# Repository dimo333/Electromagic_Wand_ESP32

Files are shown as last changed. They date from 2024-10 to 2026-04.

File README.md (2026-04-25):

# 🧙‍♂️ ESP32 手势识别魔杖项目

## 项目简介

这是一个基于 **ESP32 + MPU6050** 实现的 **手势识别电子魔杖** 项目。你可以参考本项目的文件，动手制作属于你自己的魔杖！

我还提供了训练代码，你可以根据自己设计的动作“训练法术”。如果你有更好的创意或代码，欢迎交流、学习与分享！

- 📘 [完整项目地址github](https://github.com/dimo333/Electromagic_Wand_ESP32)
- 📘 [完整项目地址gitee](https://gitee.com/dimo666/Electromagic_Wand_ESP32/tree/main)
- 📘 [PCB文件地址oshwhub](https://oshwhub.com/6dimo9/electromagic_wand_esp32)
---

## 🚀 快速开始

我已编写详细的图文教程和环境配置指南：

- 📘 [教程文档github](https://github.com/dimo333/Electromagic_Wand_ESP32/tree/main/docs/tutorial)
- 📘 [教程文档gitee](https://gitee.com/dimo666/Electromagic_Wand_ESP32/tree/main/docs/tutorial)
- 📺 [B站视频教程（基础演示）](https://www.bilibili.com/video/BV1NtwreXEzg)

---

## 🛠 遇到问题？

请尝试以下方法：

1. 仔细检查是否遗漏了教程中的某一步。
2. 根据[H_elp](https://github.com/dimo333/Electromagic_Wand_ESP32/tree/main/docs/H_elp)文档进行自救<br>
3. 复制错误信息，使用搜索引擎或 AI 工具查找答案。
4. 加入 QQ 群：**884880944**。
5. B站后台私信我：[dimo333](https://space.bilibili.com/)。
6. 发送邮件联系我：
   - 📧 dimo333mail@gmail.com（注意拼写）
   - 📧 3180405726@qq.com

---

## ✨ 魔杖具备哪些功能？

魔杖实现了基础的手势识别，基于此可扩展出以下功能：

- 📡 红外信号复制与发送（遥控家电）
- 🖱 模拟鼠标（如飞鼠操作）
- ⌨️ 模拟键盘（快捷输入）
- 📶 蓝牙 / WiFi 通信
  - 可接入 HomeAssistant 实现智能家居联动
  - 接入米家app控制米家设备

---

## 💰 硬件清单与预算

### 🔧 模块连接（推荐入门版）

- 成本约：**15 元**
- 组件清单：
  - ESP32-C3 SuperMini（4MB Flash）
  - MPU6050 陀螺仪模块
  - 按键模块（可选）

### 🛠 自制 PCB（进阶推荐）

- 成本约：**70 元**
- 推荐下单平台：嘉立创 / 立创商城
- 所需内容：
  - PCB 电路板（支持免费打样）
  - PCB 元件
  - 芯片：ESP32-C3FH4、MPU6050 等

---

## 🧞 想直接玩，有没有捷径？

有的，兄弟有的！不想动手，那就动点钱：

- 加入 QQ 群，问问有没有大佬愿意出售焊接好的板子。
- 私聊我，看看我这还有没有多余的现成板子。

---

## 📁 项目结构

```text
├── docs                # 项目文档、图文教程、使用说明
├── Software            # 软件代码（数据收集、训练等）
├── Hardware            # 原理图、电路板设计文件、3D外壳模型等硬件相关资料
├── 3D_Print            # 3D外壳模型
├── lib                # 库文件（如库压缩包、工具函数）
```
---
## 复刻路线
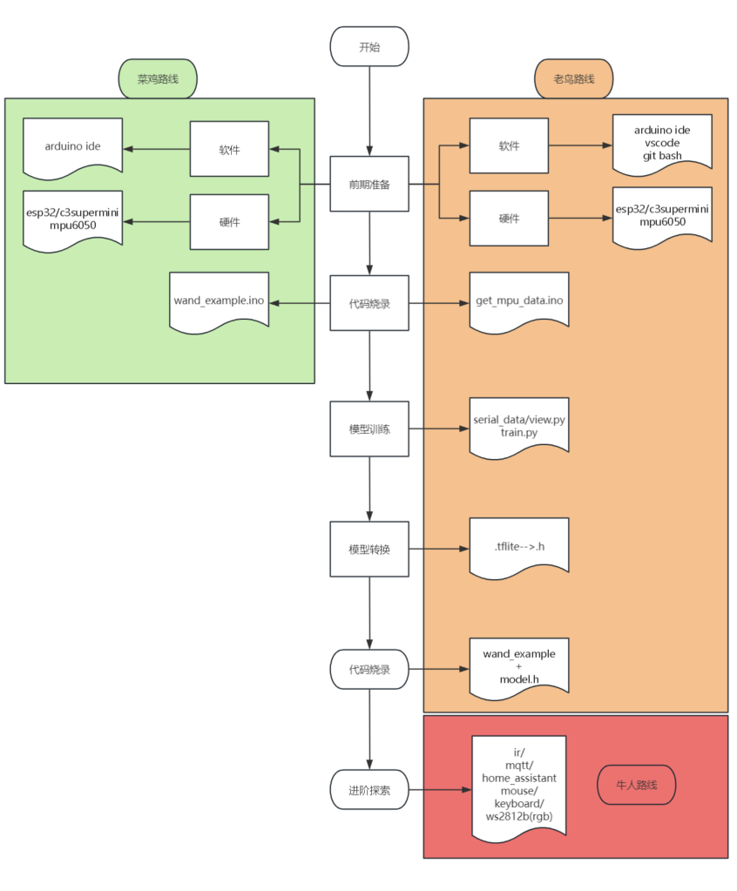
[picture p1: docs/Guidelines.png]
复刻路线


## 🤝 鸣谢与参考

* [MagicWand](https://github.com/Songyeyaosong/MagicWand) - 感谢其最早实现了赛博魔杖的底层功能，为本项目的二次开发提供了参考。
* [esp32_mouse_keyboard](https://github.com/asterics/esp32_mouse_keyboard) - 感谢其提供的 BLE 鼠标与键盘模拟功能，极大丰富了魔杖的交互能力。

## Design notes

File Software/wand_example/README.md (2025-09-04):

重要提醒：
wand是魔杖最终烧录进去的代码，记得检查一下代码靠下方有一个数据打印的输出，需要检查一下和自己使用的轴，getmpudata录数据的轴是不是同样的轴！！！！
在getmpudata里面：
Serial.print(Ox);
Serial.print(",");
Serial.print(Oz);
那么这就是使用的x和z轴，在wand底下找到和这个相似的代码，修改成一样的
在wand_example里面：  
input[i * input_dim] = Ox;
input[i * input_dim + 1] = Oz;
这一段就是输入轴的数据了，请务必保证和上面是对应的。

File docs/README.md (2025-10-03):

## 📁 文件结构

```text
├── H_elp                   # 自救指南
├── HomeAssistant-Mi_Home   # 如何连接HomeAssistant与米家
├── gestures                # 手势动作图片参考
├── others                  # 一些图片参考
├── tutorial                # 使用教程
├── Guidelines.png          # 一张简易的路线图
```
---
我花了很多时间和精力来编写这些教程，但仍然会有我无法预想到的bug存在。<br>
如果你在根据图文教程使用的过程中遇到了问题，<br>
可以按以下步骤来排查：<br>
1、反复检查是否遗漏哪一步步骤<br>
2、根据[H_elp](https://github.com/dimo333/Electromagic_Wand_ESP32/tree/main/docs/H_elp)文档进行自救<br>
3、通过QQ群进行提问（提问请按照群公告的格式来，这会更快地获得答复）<br>

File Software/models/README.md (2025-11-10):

models
===
简述：动作（手势）的模型与数据集<br>
来源：dimo333<br>

注意事项：<br>
代码版本较旧，部分参数可能并非最新最优，请自行修改<br>
1030_5为64hz2s  ox+oz轴   24年10月30日上传（旧版）<br>
0908_6为100hz2s oy+oz轴   25年09月08日上传（新版，亲测识别率有90%）<br>
0922_6为100hz2s oy+oz轴   25年09月22日上传（新版，手势幅度更大，更自然，亲测识别效果95%）
数据集中50组为一个动作（手势）数据，你可以直接使用我训练好的模型<br>
也可以单独使用数据集自行训练<br>
注意64hz需要将train中timesteps改为128，100hz改为200<br>

---

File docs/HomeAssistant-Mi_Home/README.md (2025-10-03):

## 📁 文件结构

```text
├── HomeAssistant_with_MI_Home      # Ha及米家搭建教程
├── BY-GT8_with_MI_Hoem             # 模块连接米家教程
├── BY-GT8                          # 模块手册
```
---

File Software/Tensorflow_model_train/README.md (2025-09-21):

Tensorflow_model_train
===
简述：用于训练动作（手势）的文件<br>
来源：dimo333<br>

使用方法：<br>
1、首先请确保你认真并仔细的看过了图文教程中关于环境安装的部分<br>
2、训练出来的模型文件是.tflite后缀，需要转成.h才能写进ESP32<br>
3、在lwindows的git bash（或者Linux系统）运行这段代码将.tflite转成.h：<br>
4、 xxd -i model.tflite > model.h

注意事项：<br>
代码版本较旧，部分参数可能并非最新最优，请自行修改<br>
动作（手势）训练涉及到魔杖的核心内容之一，其中动作（手势）数据的录入需要极大的耐心和定力。<br>
用群友的话来说“这是一场魔杖选择主人巫师的过程”<br>
所以请量力而行<br>

---
---

代码与工具<br>
===

serial_data.py<br>
简述：用于收集数据并转写至data_x/y.csv的代码，为后续train.py做数据收集工作<br>
来源：dimo333<br>

---

train.py<br>
简述：用于训练动作（手势）用的代码，需要转换格式才可供wand使用<br>
来源：dimo333<br>

---

serial_data_show.py<br>
简述：基于serial_data.py改写而来，可以在收集数据的时候直观的查看动作（手势）数据的质量（波形）<br>
来源：dimo333<br>

---

view.py<br>
简述：用于直观的查看动作（手势）数据的质量（波形），需要将待查看的数据存放于show.csv文件内<br>
来源：由群内“雪云”大佬提供<br>

---

show2.py<br>
简述：受群内“雪云”大佬的启发改写，用于直观的查看动作（手势）数据的质量（波形），需要将待查看的数据存放于show.csv文件内<br>
来源：dimo333<br>

---

Dimo333_Data_Management_Tool.py<br>
简述：管理动作（手势）数据的质量（波形）的工具，需要将待查看的数据存放于show.csv文件内<br>
来源：dimo333<br>

---

注意事项：<br>
代码版本较旧，部分参数可能并非最新最优，请自行修改<br>
serial_data.py与train.py共同构成魔杖训练的主体架构，其它代码属于辅助工具<br>
因为后续魔杖的采样由64hz2s修改至100hz2s，所以除主体架构外的三个辅助代码均围绕新采样率开发，使用时注意数据格式的兼容性<br>

---

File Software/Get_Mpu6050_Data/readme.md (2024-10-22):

这个代码可以获取mpu6050的数据<br/>
使用时请确保mpu6050的scl引脚和sda引脚与esp单片机正确的连接<br/>
如果不清楚引脚的请查看库里关于esp的资料<br>

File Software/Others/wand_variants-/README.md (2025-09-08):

wand_ir_get_send
===
简述：集成手势识别与红外学习再发射的魔杖文件
来源：dimo333
注意事项：代码基于wand_example修改而来，部分参数可能并非最新最优，请自行修改

---

wand_with_mqtt
===
简述：集成手势识别与mqtt的魔杖文件
来源：由群内“星”大佬提供
注意事项：代码基于wand_example修改而来，部分参数可能并非最新最优，请自行修改

---

（如果你都研究到这一份代码了，想必对你来说应该是小菜一碟）

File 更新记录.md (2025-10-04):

更新内容：
===
2025/10/04<br>
---
1、上传了新的手势动作模型0922_6（识别效果较好，更为自然）<br>

2025/10/03<br>
---
1、上传了图文教程系列中关于魔杖连接HomeAssistant、米家、第三方连接的图文教程<br>
2、上传了适用于手势米家魔杖（v3.1）适用的代码<br>

2025/10/02<br>
---
1、重制了所有图文教程并做了更详细的分类<br>
2、新增H_elp错误问题集<br>
3、修复了教程中已知的所有bug<br>

2025/09/21<br>
---
1、上传了动作（手势）数据的质量（波形）的管理工具（Dimo333_Data_Management_Tool.py）。可批量化处理已有的动作（手势）数据<br>

2025/09/08<br>
---
1、更新了getmpudata数据输出。在数据输出处*9.8使得数据变动更明显。<br>
2、更新wand_example数据输出。适配于getmpudata收集的扩大的数据所训练出来的模型。<br>
3、上传了models里的模型和数据集。可以直接使用训练好的模型或数据集自主训练。<br>
4、上传了Tensorflow_model_train里的工具函数（view、show2、serial_data_show)。更好的帮助数据集的录入。<br>
5、整理了位于Software/Others底下的代码的注释及相关信息。<br>

2025/08/31
---
1、全面整理了仓库<br>

---

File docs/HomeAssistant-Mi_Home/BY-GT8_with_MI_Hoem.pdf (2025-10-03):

这里讲的是另外一种接入米家的方法，这里介绍的模块是 BY-GT8
相比于 ha 做中转，使用第三方模块接入会更加简单，但是简单不意味着省钱
使用 bygt8 需要一个米家网关才能连接到米家 app，常见的米家网关设备如小米音响。 我使用的就是一个红米音响

由于小米开始限制这种第三方模块，使得很多地方都购买不到，在咸鱼等海鲜市场上也 是买一个少一个，我手上还有一部分，如果你需要的话可以来找我购买。

后续我也会研究其它的模块来替换第三方模块，在这之前，先凑活用吧

关于 bygt8 的具体使用方法还请看手册，仔细看一遍就懂了

dimo333

dimo333

dimo333

dimo333

dimo333

dimo333

dimo333

dimo333

dimo333

dimo333

dimo333

dimo333

dimo333

dimo333

dimo333

dimo333

dimo333

dimo333

dimo333

dimo333

dimo333

dimo333

dimo333

dimo333

dimo333

dimo333

dimo333

dimo333

dimo333

dimo333

dimo333

dimo333

dimo333

dimo333

dimo333

dimo333

dimo333

dimo333

dimo333

dimo333

dimo333

dimo333

dimo333

dimo333

dimo333

dimo333

dimo333

dimo333

dimo333

dimo333

dimo333

dimo333

dimo333

dimo333

dimo333

dimo333

dimo333

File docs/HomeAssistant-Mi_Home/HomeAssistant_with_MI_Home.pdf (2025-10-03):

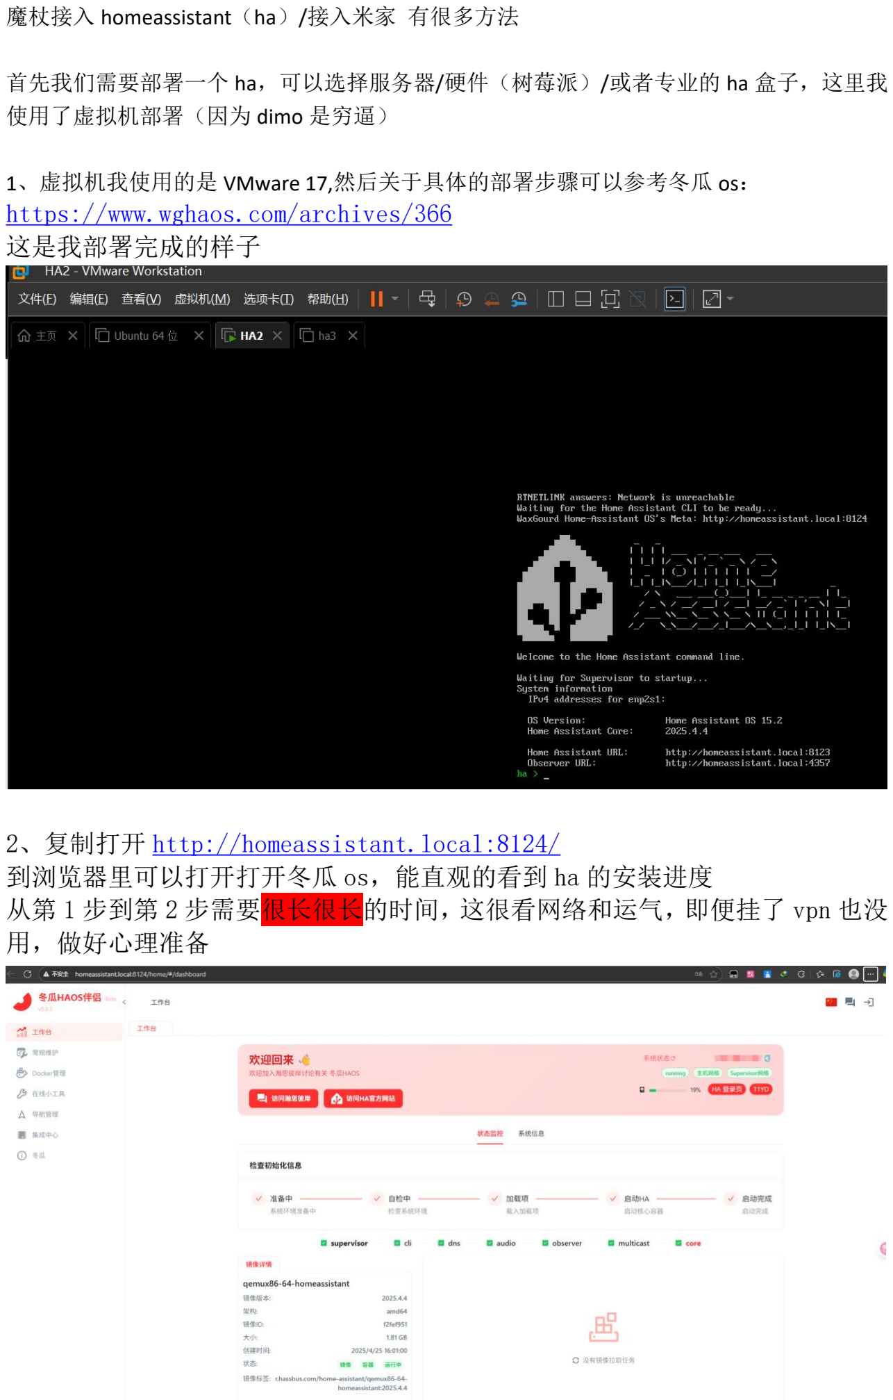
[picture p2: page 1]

魔杖接入 homeassistant（ha）/接入米家 有很多方法

首先我们需要部署一个 ha，可以选择服务器/硬件（树莓派）/或者专业的 ha 盒子，这里我 使用了虚拟机部署（因为 dimo 是穷逼）

1、虚拟机我使用的是 VMware 17,然后关于具体的部署步骤可以参考冬瓜 os： https://www.wghaos.com/archives/366
这是我部署完成的样子

2、复制打开 http://homeassistant.local:8124/
到浏览器里可以打开打开冬瓜 os，能直观的看到 ha 的安装进度
从第 1 步到第 2 步需要很长很长的时间，这很看网络和运气，即便挂了 vpn 也没 用，做好心理准备

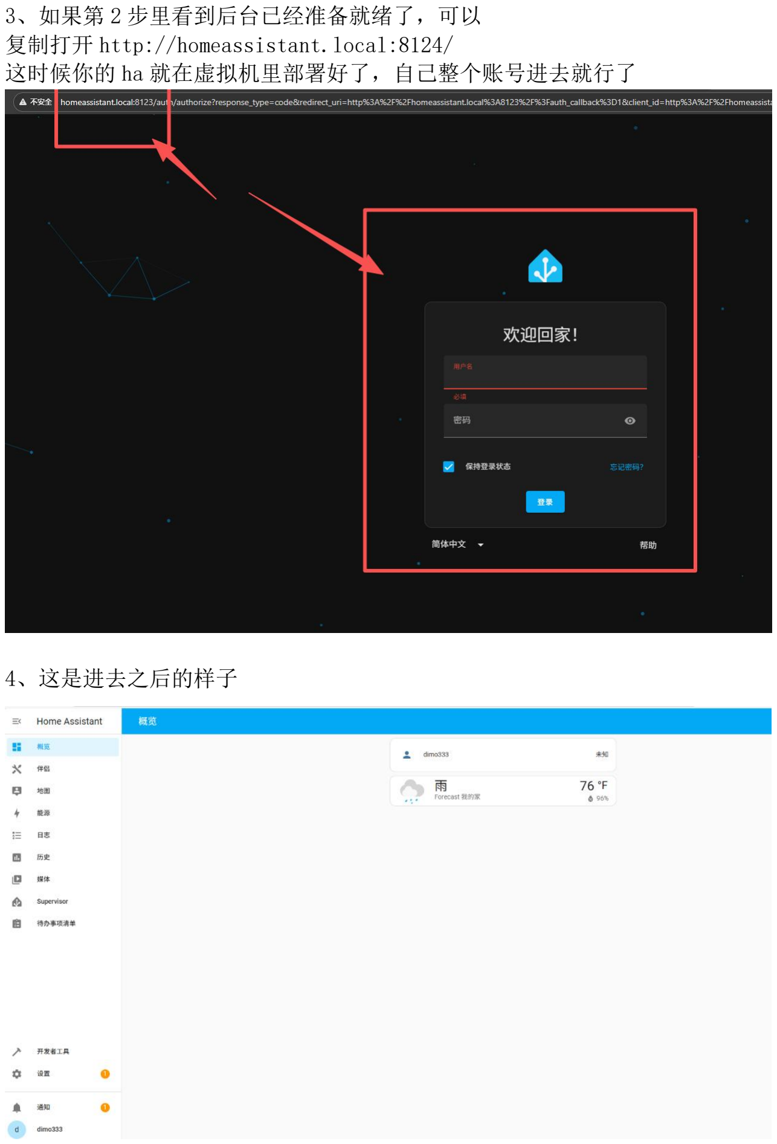
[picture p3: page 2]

3、如果第 2 步里看到后台已经准备就绪了，可以
复制打开 http://homeassistant.local:8124/
这时候你的 ha 就在虚拟机里部署好了，自己整个账号进去就行了

4、这是进去之后的样子

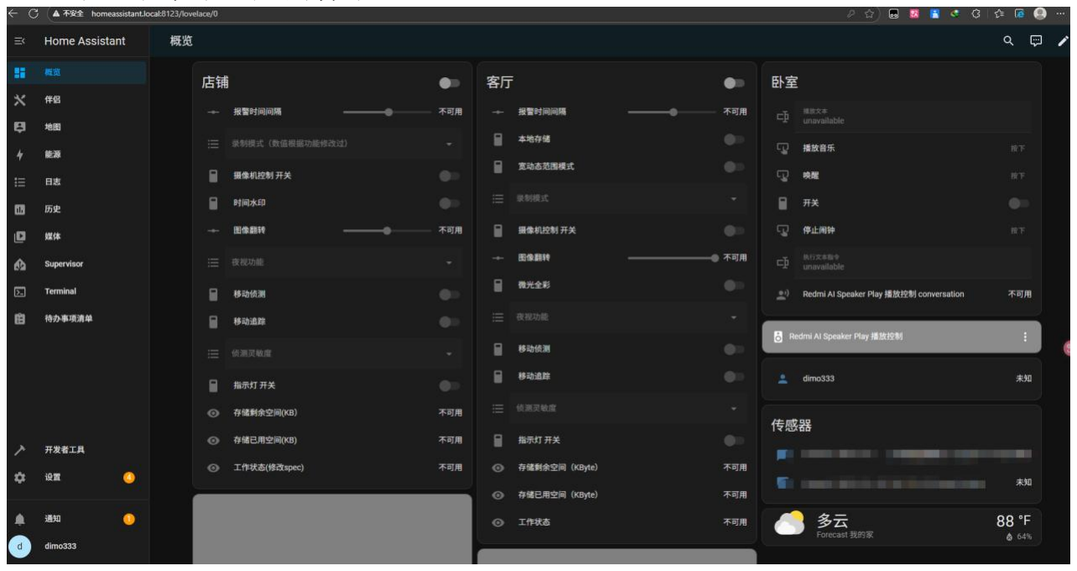
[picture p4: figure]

这是添加了米家之后的样子

5、接下来是需要配置 ha 里面的环境，用于 mqtt 的通信 可以参考这个视频：
https://www.bilibili.com/video/BV1yZ421M7NR
从 5 分 29 至 9 分 26
由于我上次跑通 mqtt 的方案是在 5 月份，很多东西也都忘记了，所以以下内容 仅供参考

6、跟着做就完了，和视频里相比还是漏了很多步骤，请综合性参考后再操作

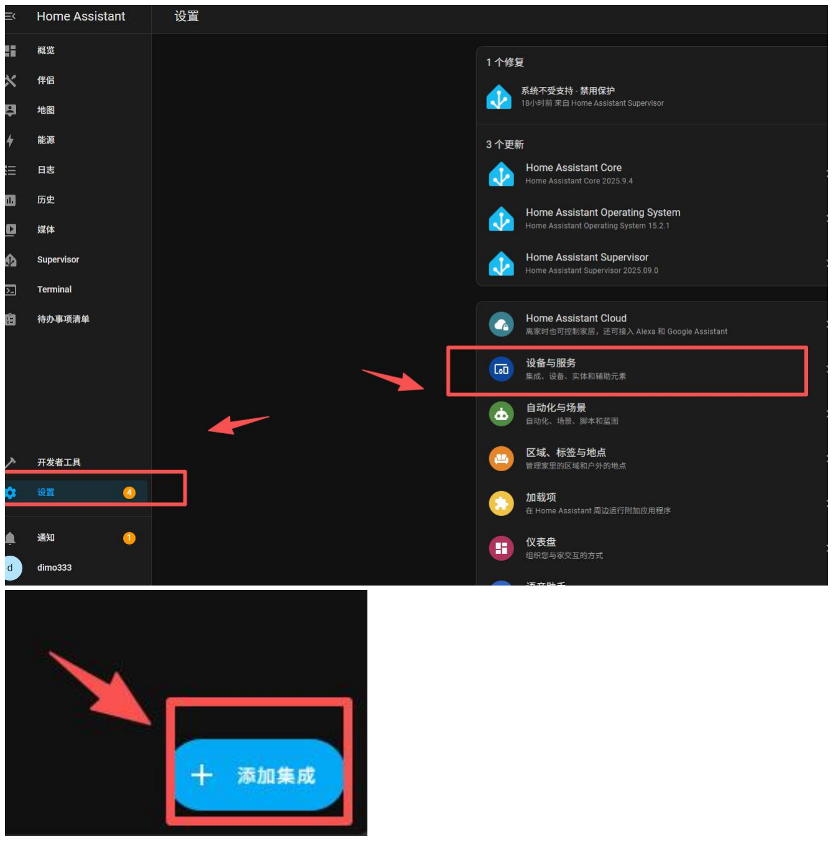
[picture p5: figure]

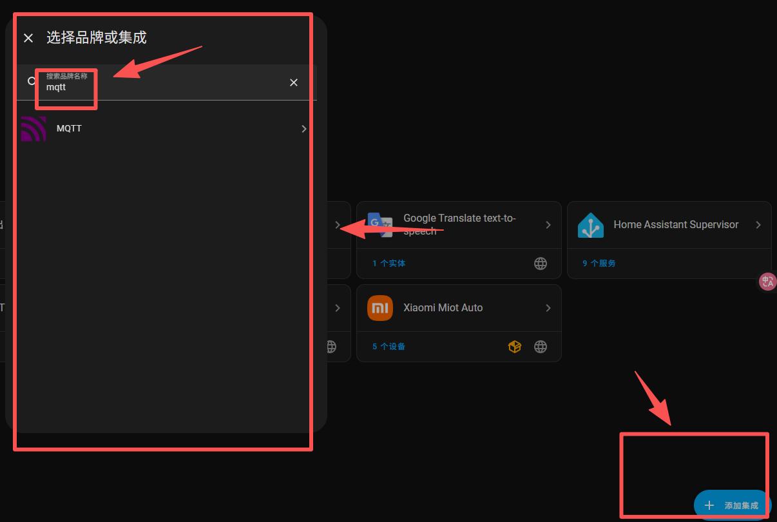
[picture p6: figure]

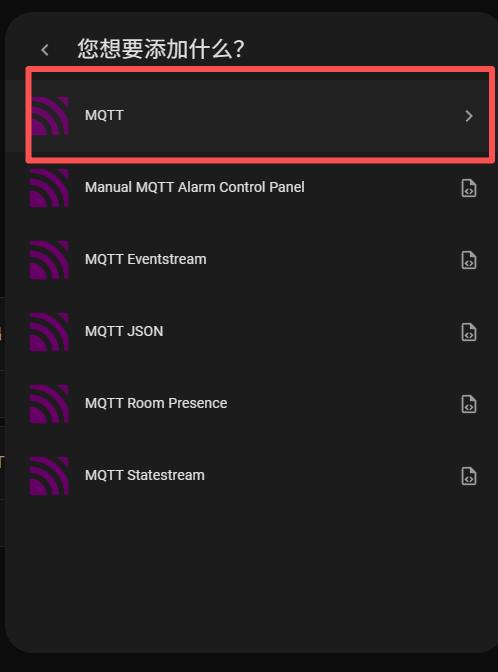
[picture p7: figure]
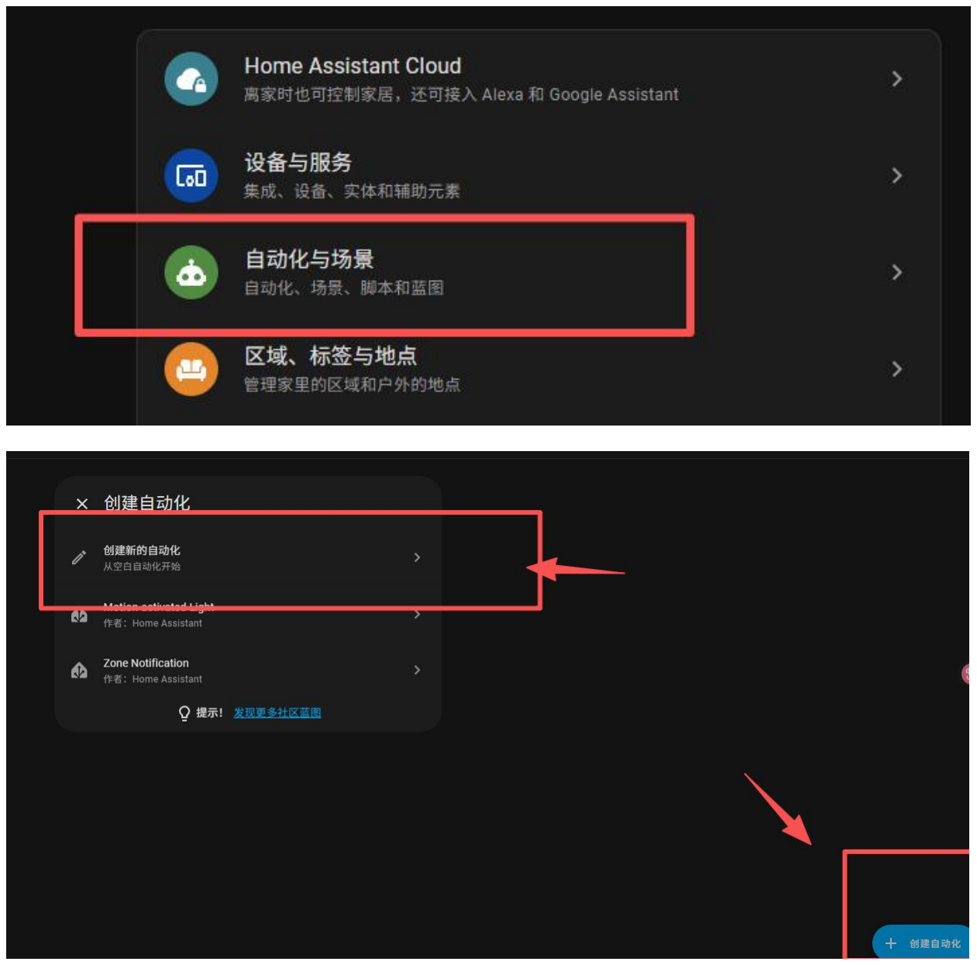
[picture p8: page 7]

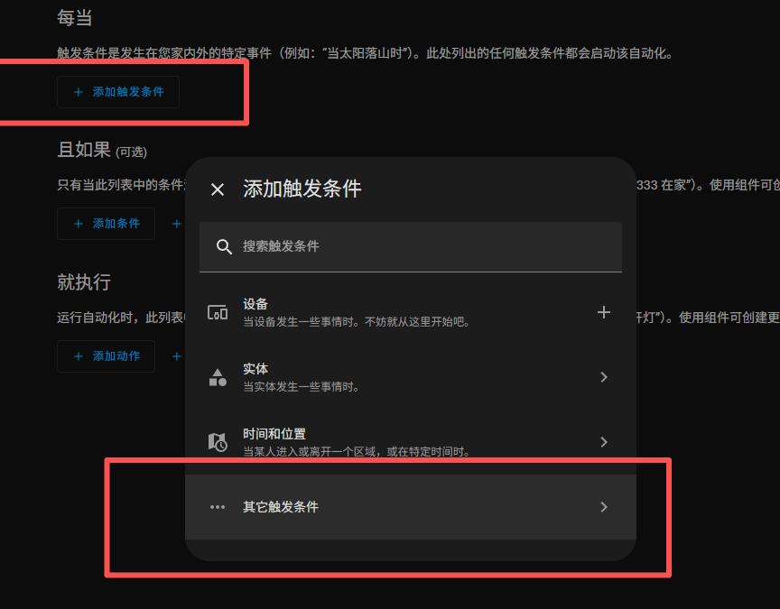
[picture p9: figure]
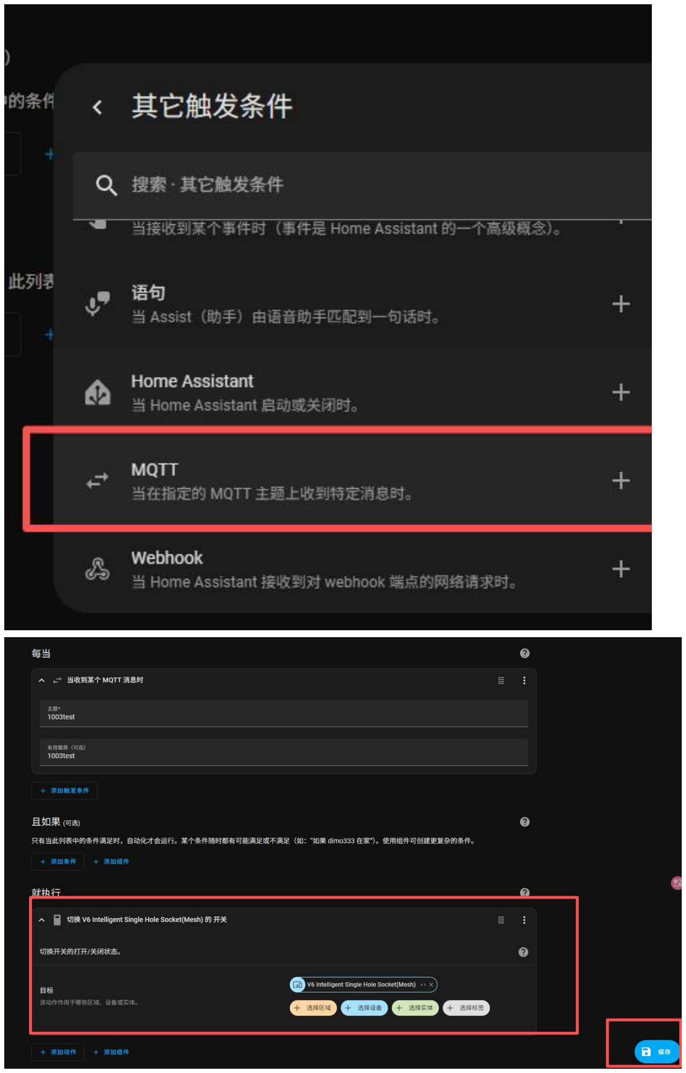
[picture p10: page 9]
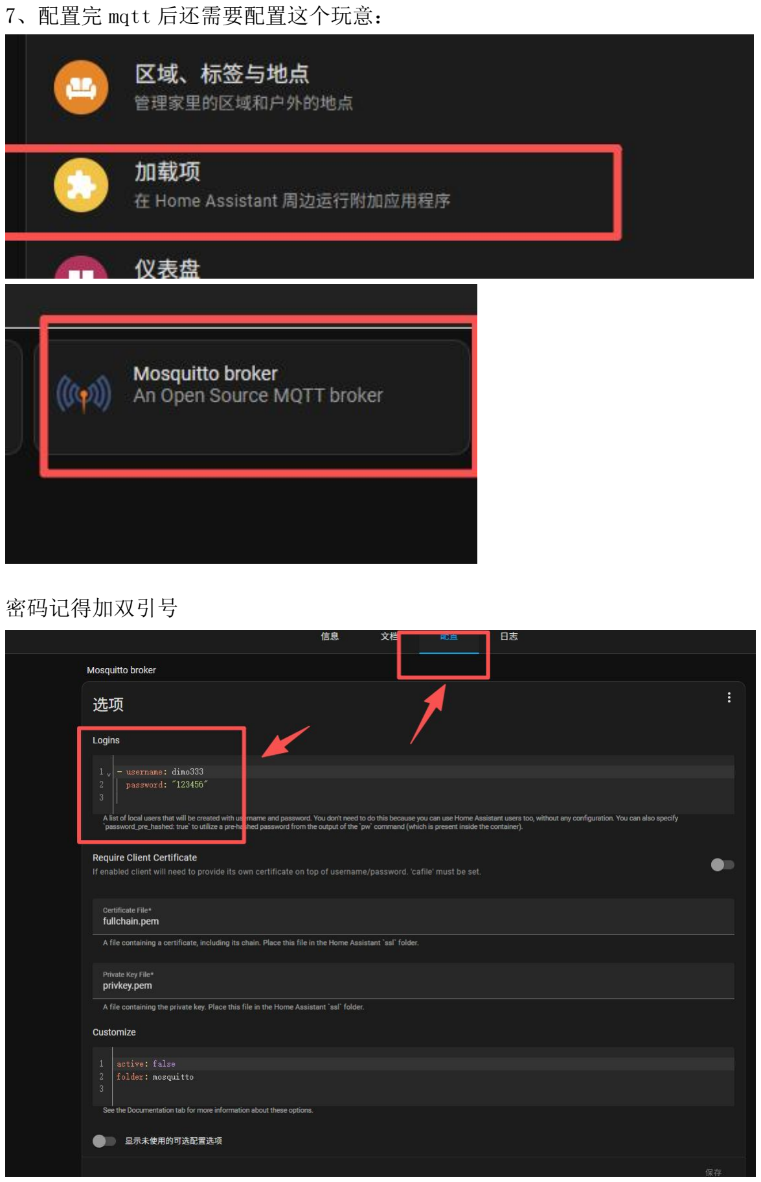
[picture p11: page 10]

7、配置完 mqtt 后还需要配置这个玩意：

密码记得加双引号

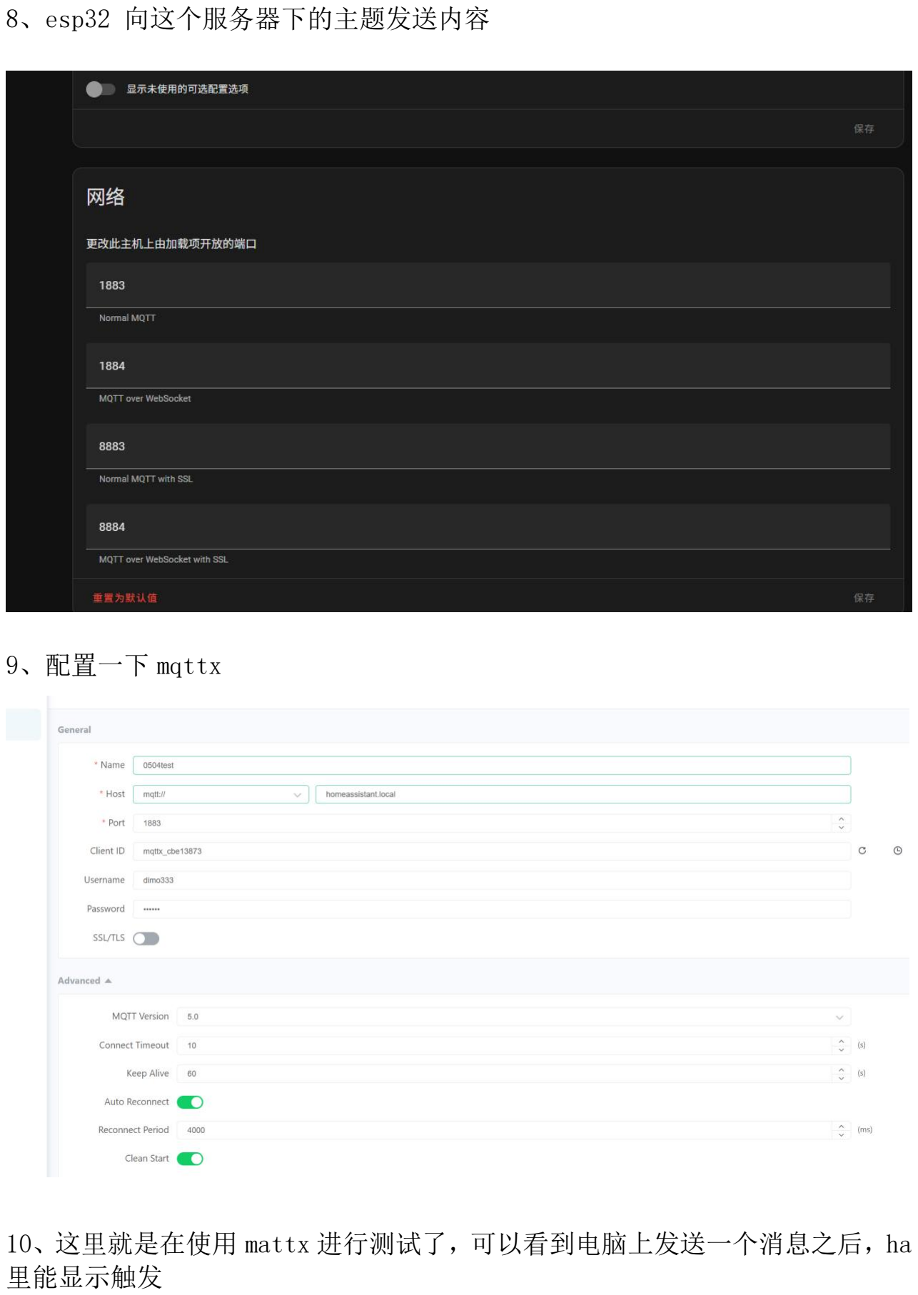
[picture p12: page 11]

8、esp32 向这个服务器下的主题发送内容

9、配置一下 mqttx

10、这里就是在使用 mattx 进行测试了，可以看到电脑上发送一个消息之后，ha 里能显示触发

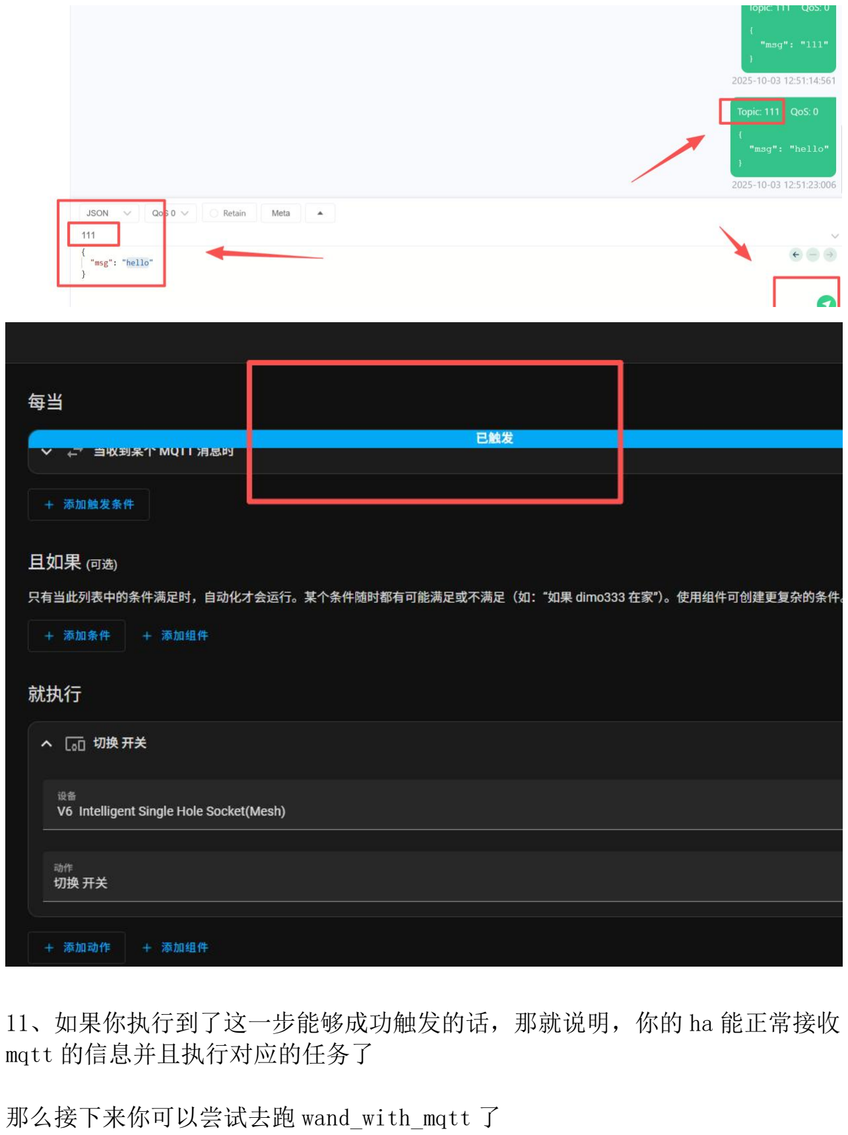
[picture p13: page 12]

11、如果你执行到了这一步能够成功触发的话，那就说明，你的 ha 能正常接收 mqtt 的信息并且执行对应的任务了

那么接下来你可以尝试去跑 wand_with_mqtt 了

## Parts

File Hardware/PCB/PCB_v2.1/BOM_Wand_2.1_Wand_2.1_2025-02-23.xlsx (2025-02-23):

No. | Quantity | Comment | Designator | Footprint | Value | Manufacturer Part | Manufacturer | Supplier Part | Supplier
1 | 5 | 100nF | C1,C6,C7,C8,C11 | C0402 | 100nF | CC0402KRX7R7BB104 | YAGEO(国巨) | C60474 | LCSC
2 | 1 | 10nF | C2 | C0402 | 10nF | CC0402KRX7R9BB103 | YAGEO(国巨) | C60133 | LCSC
3 | 5 | 1uF | C3,C10,C12,C13,C18 | C0402 | 1uF | CL05A105KQ5NNNC | SAMSUNG(三星) | C107372 | LCSC
4 | 2 | 15pF | C4,C5 | C0402 | 15pF | 0402CG150J500NT | FH(风华) | C1548 | LCSC
5 | 2 | 10uF | C9,C14 | C0402 | 10uF | CL05A106MP5NUNC | SAMSUNG(三星) | C315248 | LCSC
6 | 1 | 0.1uF 0603 | C28 | C0603 | 0.1uF 0603 | CC0603JRNPO9BN101 | YAGEO(国巨) |  | LCSC
7 | 1 | 100nF 1206 Ta | C29 | CAP-SMD_L3.2-W1.6-RD | 100nF 1206 Ta | CA45-A-35V-0.1UF-K | CEC(振华新云) |  | LCSC
8 | 1 | 2.2uF | C30 | C0603 | 2.2uF | CL10A225KO8NNNC | SAMSUNG(三星) | C23630 | LCSC
9 | 1 | 100nF | C31 | C0603 | 100nF | CGA0603X7R104K500JT | HRE(芯声) | C6119867 | LCSC
10 | 2 | NC | C32,C33 | C0402 | NC | CL05B104KO5NNNC | SAMSUNG(三星) |  | LCSC
11 | 1 | HC-1.25-2AW | CN2 | CONN-TH_2P-P1.25_HCTL_HC-1.25-2AW |  | HC-1.25-2AW | HCTL(华灿天禄) | C2845535 | LCSC
12 | 1 | TS24CA | Control1 | SW-SMD_TS24CA |  | TS24CA | SHOU HAN(首韩) | C393942 | LCSC
13 | 1 | SD103AWS | D1 | SOD-323_L1.8-W1.3-LS2.5-RD |  | SD103AWS | Hottech(合科泰) | C181207 | LCSC
14 | 1 | PZ254-2-03-W-8.5 | H6 | HDR-TH_6P-P2.54-H-M-R2-C3-S2.54-W12.3-N |  | PZ254-2-03-W-8.5 | HCTL(华灿天禄) | C2894983 | LCSC
15 | 1 | 2nH | L1 | L0402 | 2nH | LQG15HS2N0S02D | muRata(村田) | C18216 | LCSC
16 | 2 | SZYY0402W | LED1,LED2 | LED0402-RD_WHITE |  | SZYY0402W | yongyu(永裕光电) | C434448 | LCSC
17 | 1 | 510Ω | R1 | R0402 | 510Ω | RC0402JR-07510RL | YAGEO(国巨) | C137860 | LCSC
18 | 5 | 10kΩ | R2,R3,R4,R5,R7 | R0402 | 10kΩ | RC0402FR-0710KL | YAGEO(国巨) | C60490 | LCSC
19 | 2 | 5.1kΩ | R6,R8 | R0402 | 5.1kΩ | 0402WGF5101TCE | UNI-ROYAL(厚声) | C25905 | LCSC
20 | 2 | 10kΩ | R39,R40 | R0603 | 10kΩ | 0603WAF1002T5E | UNI-ROYAL(厚声) | C25804 | LCSC
21 | 1 | 4.7kΩ 0603 | R41 | R0603 | 4.7kΩ 0603 | 0603WAF1002T5E | UNI-ROYAL(厚声) |  | LCSC
22 | 1 | 0R | R42 | R0402 | 0R
23 | 2 | TS-1088R-02026 | SW1,SW2 | SW-SMD_L3.9-W3.0-P4.45 |  | TS-1088R-02026 | XUNPU(讯普) | C455280 | LCSC
24 | 1 | TA-3522-A3 | SW3 | SW-TH_3P-L9.1-W3.5-P2.50-A3 |  | TA-3522-A3 | Yuandi(元迪) | C514011 | LCSC
25 | 1 | ESP32-C3FH4 | U1 | QFN-32_L5.0-W5.0-P0.50-TL-EP3.7 |  | ESP32-C3FH4 | ESPRESSIF(乐鑫) | C2858491 | LCSC
26 | 1 | RT9013-33GB | U2 | SOT-23-5_L3.0-W1.7-P0.95-LS2.8-BL |  | RT9013-33GB | RICHTEK(立锜) | C47773 | LCSC
27 | 1 | MPU-6050 | U8 | QFN-24_L4.0-W4.0-P0.50-BL-EP2.7 |  | MPU-6050 | TDK InvenSense(应美盛) | C24112 | LCSC
28 | 1 | ANT3216LL00R2400A | U9 | ANT-SMD_L3.2-W1.6 |  | ANT3216LL00R2400A | YAGEO(国巨) | C293767 | LCSC
29 | 1 | TYPE-C-31-M-12 | USBC1 | USB-C_SMD-TYPE-C-31-M-12 |  | TYPE-C-31-M-12 | 韩国韩荣 | C165948 | LCSC
30 | 1 | 40MHz | X1 | OSC-SMD_4P-L3.2-W2.5-BL_SIT8008BI | 40MHz | X322540MPB4SI | YXC(扬兴晶振) | C9010 | LCSC

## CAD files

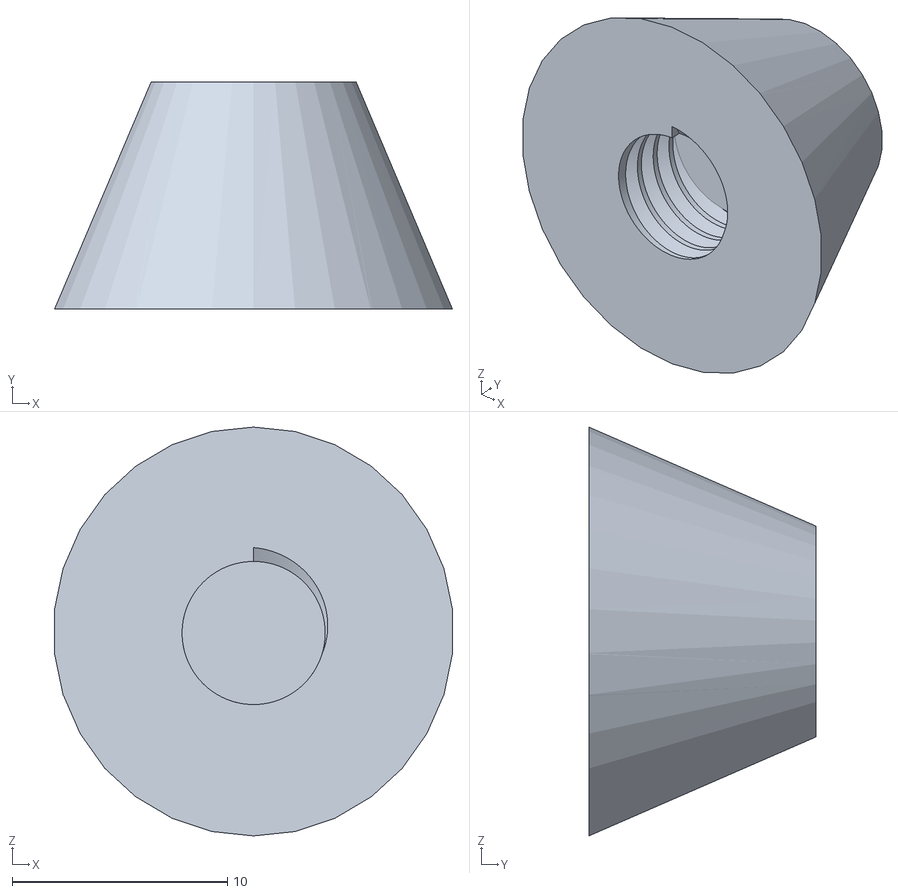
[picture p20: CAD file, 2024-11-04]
3D_Print/v2.0/6_尖端.stl
18.5 x 10.6 x 19.0

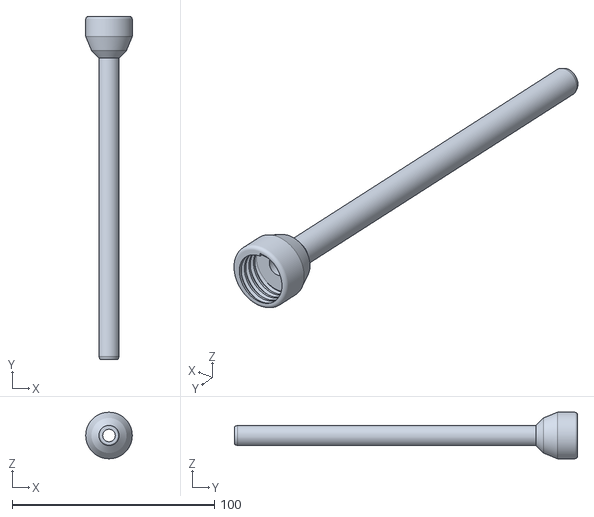
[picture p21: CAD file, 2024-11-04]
3D_Print/v2.0/2_尾.stl
23.0 x 169.5 x 23.0

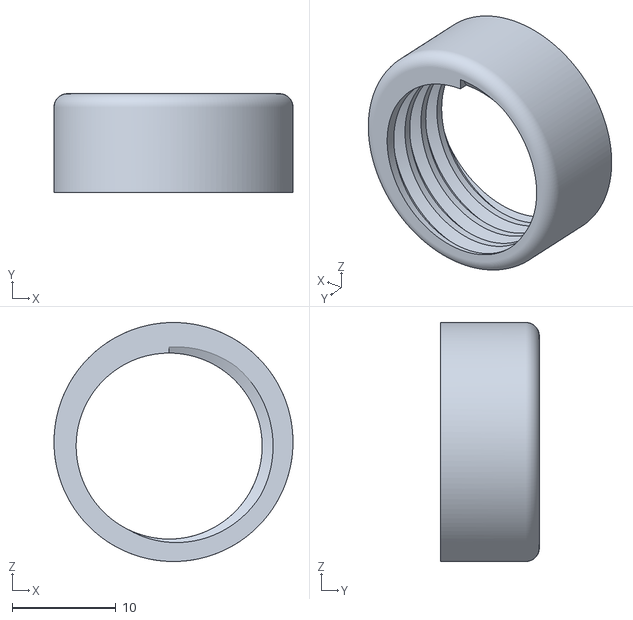
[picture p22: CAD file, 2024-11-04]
3D_Print/v2.0/1_固定端.stl
23.0 x 9.50 x 23.0

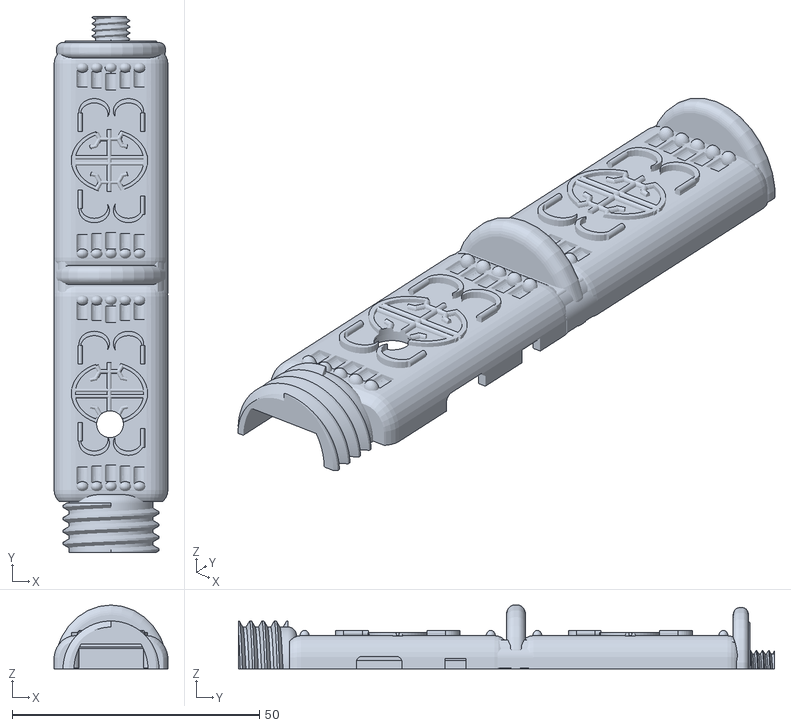
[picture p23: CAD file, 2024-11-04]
3D_Print/v2.0/4_壳1.stl
23.0 x 108.4 x 12.9

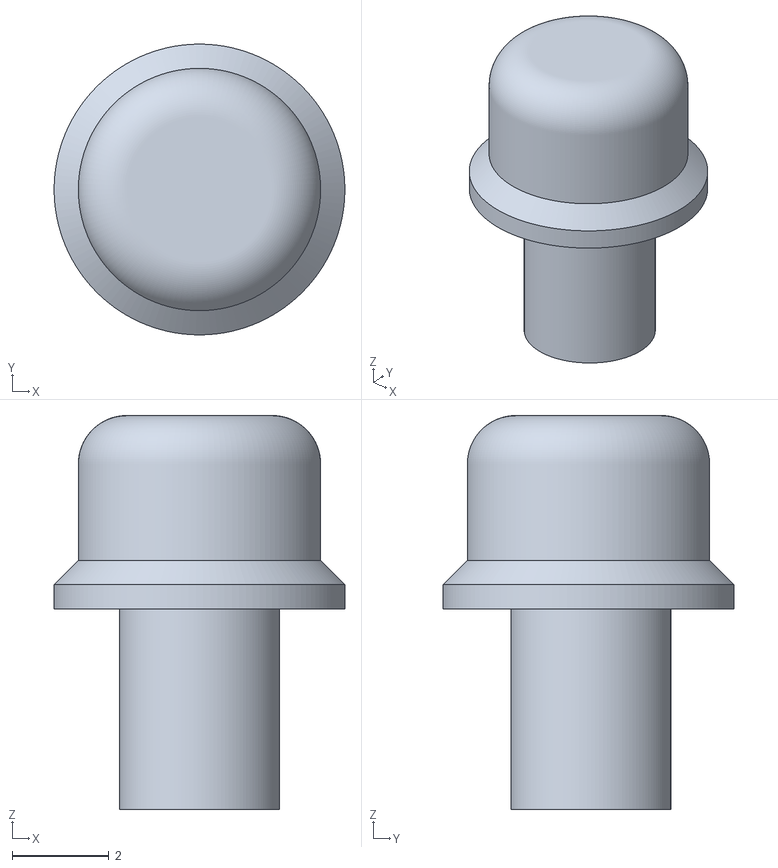
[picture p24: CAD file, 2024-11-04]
3D_Print/v2.0/3_按键.stl
6.00 x 6.00 x 8.13

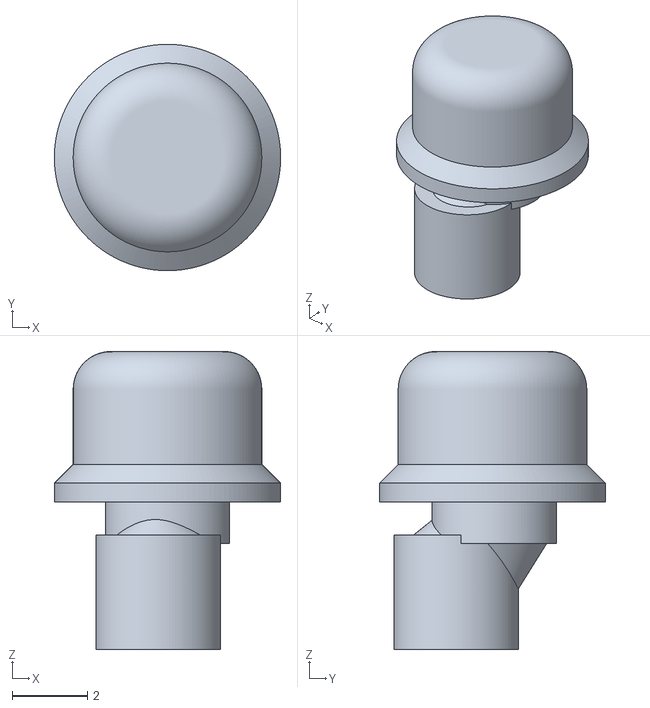
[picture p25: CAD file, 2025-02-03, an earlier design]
3D_Print/v1.0/按键.stl
6.00 x 6.00 x 7.90

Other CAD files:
3D_Print/v1.0/套.stl
3D_Print/v1.0/管.stl

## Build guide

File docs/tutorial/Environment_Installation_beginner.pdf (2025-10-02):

### 以下是关于软件的安装，包括 ide 安装、 环境搭建等，如遇网络问题或意外原因 中断，请尝试使用全局 VPN

## 软件安装：arduino

这个我就不多说了，你都玩电脑了，装个软件都
不会？

## 环境搭建：arduino

要想下载 esp32，需要点击左上角 文件->首选项

dimo333

dimo333

dimo333

dimo333

dimo333

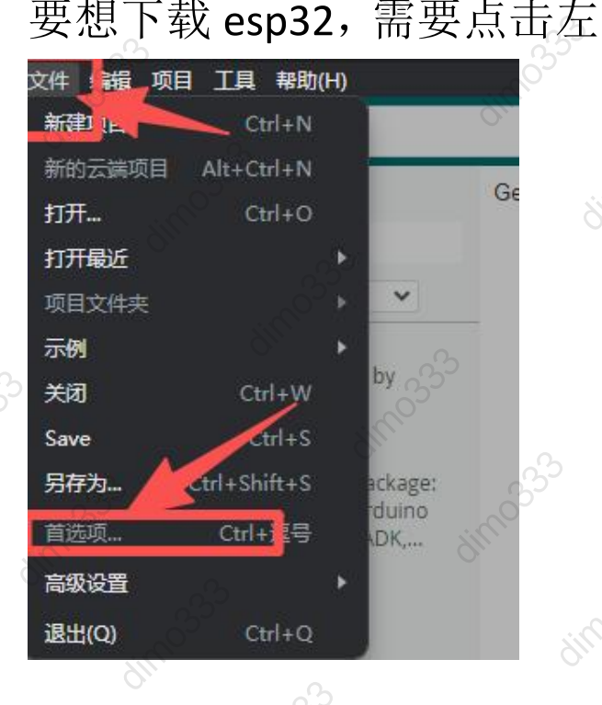
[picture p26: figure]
dimo333

dimo333

dimo333

dimo333

dimo333

dimo333

dimo333

dimo333

dimo333

dimo333

dimo333

dimo333

dimo333

dimo333

dimo333

dimo333

dimo333

dimo333

dimo333

dimo333

dimo333

dimo333

dimo333

dimo333

dimo333

dimo333

dimo333

dimo333

dimo333

dimo333

dimo333

dimo333

dimo333

dimo333

dimo333

dimo333

dimo333

dimo333

dimo333

点击打开，把 esp32 的管理器地址添加进去，我
忘记是哪个了，直接按我的全部复制进去吧，注
意一行一个：

https://dl.espressif.com/dl/package_esp32_index.j son https://espressif.github.io/arduino-esp32/package _esp32_index.json https://ghproxy.com/https://raw.githubuserconten t.com/espressif/arduino-esp32/gh-pages/package_ esp32_index.json https://git.oschina.net/dfrobot/FireBeetle-ESP32/r aw/master/package_esp32_index.json

dimo333

dimo333

dimo333

dimo333

dimo333

dimo333

dimo333

dimo333

dimo333

dimo333

dimo333

dimo333

dimo333

dimo333

dimo333

dimo333

dimo333

dimo333

dimo333

dimo333

dimo333

dimo333

dimo333

dimo333

dimo333

dimo333

dimo333

dimo333

dimo333

dimo333

dimo333

dimo333

dimo333

dimo333

dimo333

dimo333

dimo333

dimo333

dimo333

dimo333

dimo333

dimo333

dimo333

dimo333

dimo333

dimo333

dimo333

dimo333

dimo333

dimo333

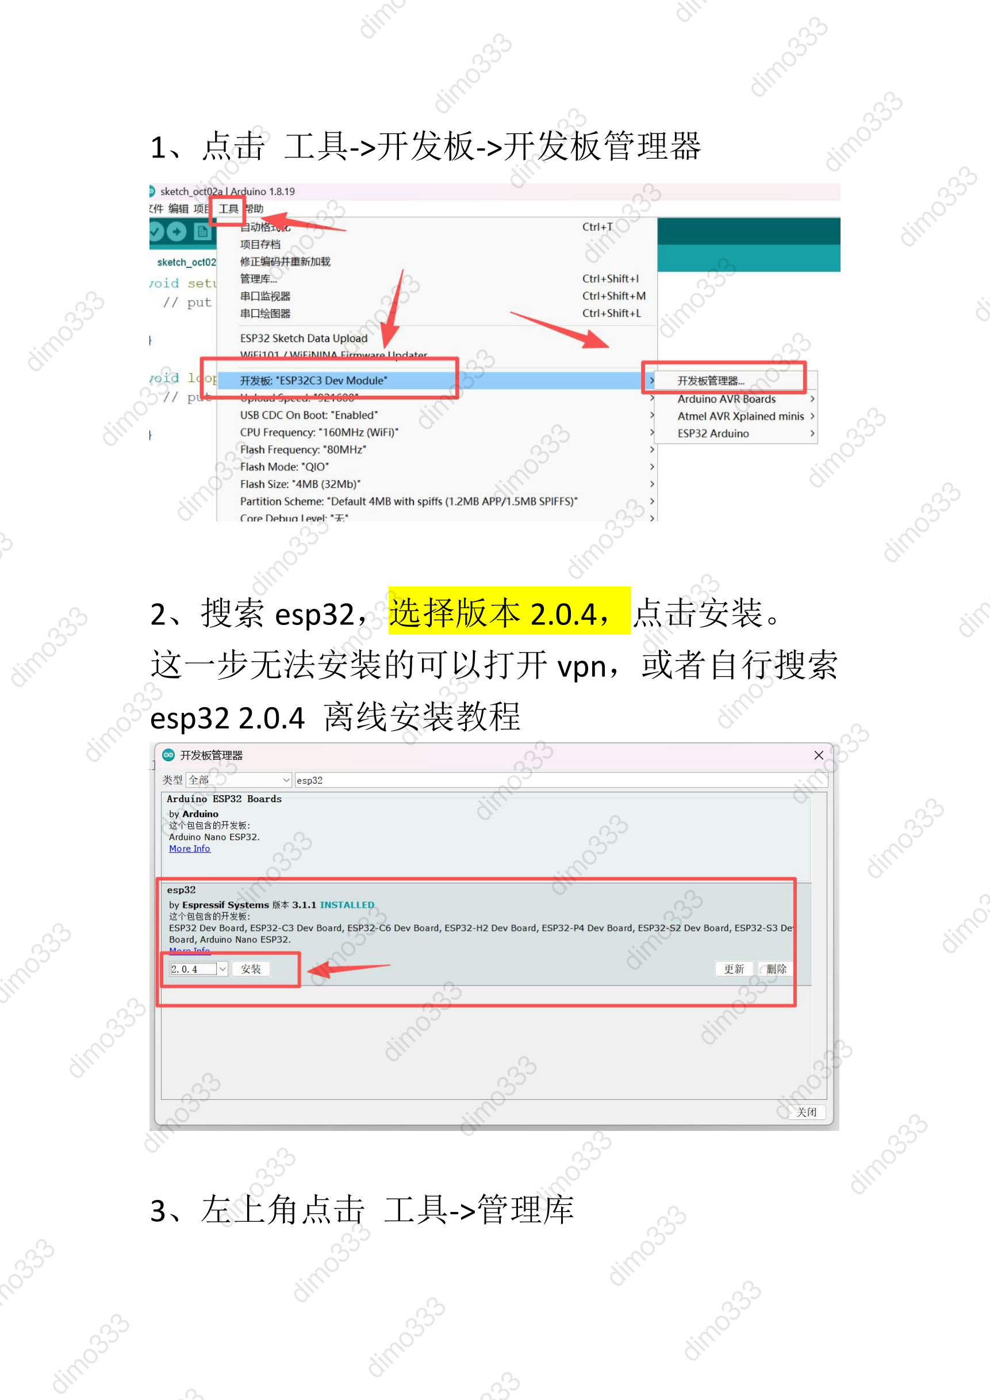
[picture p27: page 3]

1、点击 工具->开发板->开发板管理器

2、搜索 esp32，选择版本 2.0.4，点击安装。 这一步无法安装的可以打开 vpn，或者自行搜索

## esp32 2.0.4 离线安装教程

3、左上角点击 工具->管理库

dimo333

dimo333

dimo333

dimo333

dimo333

dimo333

dimo333

dimo333

dimo333

dimo333

dimo333

dimo333

dimo333

dimo333

dimo333

dimo333

dimo333

dimo333

dimo333

dimo333

dimo333

dimo333

dimo333

dimo333

dimo333

dimo333

dimo333

dimo333

dimo333

dimo333

dimo333

dimo333

dimo333

dimo333

dimo333

dimo333

dimo333

dimo333

dimo333

dimo333

dimo333

dimo333

dimo333

dimo333

dimo333

dimo333

dimo333

dimo333

dimo333

dimo333

## 安装 mpu6050 的库：

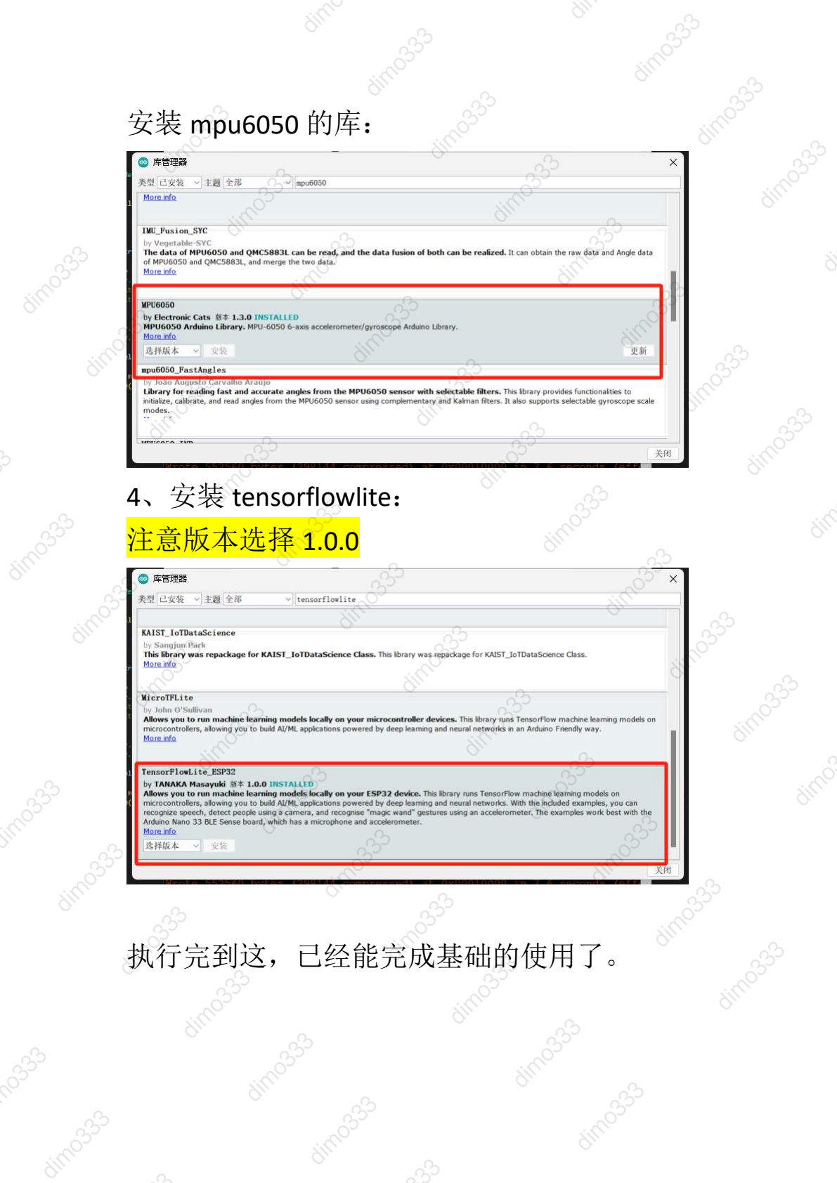
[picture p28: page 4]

## 4、安装 tensorflowlite：

注意版本选择 1.0.0

执行完到这，已经能完成基础的使用了。

dimo333

dimo333

dimo333

dimo333

dimo333

dimo333

dimo333

dimo333

dimo333

dimo333

dimo333

dimo333

dimo333

dimo333

dimo333

dimo333

dimo333

dimo333

dimo333

dimo333

dimo333

dimo333

dimo333

dimo333

dimo333

dimo333

dimo333

dimo333

dimo333

dimo333

dimo333

dimo333

dimo333

dimo333

dimo333

dimo333

dimo333

dimo333

dimo333

dimo333

dimo333

dimo333

dimo333

dimo333

dimo333

dimo333

dimo333

dimo333

dimo333

dimo333

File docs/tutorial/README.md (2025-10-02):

## 📁 项目结构

```text
├── Environment_Installation_beginner            # 基础环境搭建指南
├── Use_Process_beginner                         # 基础使用指南
├── Environment_Installation_advanced            # 进阶部分环境搭建指南
├── Use_Process_advanced                         # 进阶使用指南
```

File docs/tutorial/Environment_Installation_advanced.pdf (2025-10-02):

### 以下是关于软件的安装，包括 ide 安装、 环境搭建等，如遇网络问题或意外原因 中断，请尝试使用全局 VPN

## 9、软件安装：vscode

这个我就不多说了，你都玩电脑了，装个软件都
不会？

dimo333

dimo333

dimo333

dimo333

dimo333

dimo333

dimo333

dimo333

dimo333

dimo333

dimo333

dimo333

dimo333

dimo333

dimo333

dimo333

dimo333

dimo333

dimo333

dimo333

dimo333

dimo333

dimo333

dimo333

dimo333

dimo333

dimo333

dimo333

dimo333

dimo333

dimo333

dimo333

dimo333

dimo333

dimo333

dimo333

dimo333

dimo333

dimo333

dimo333

dimo333

dimo333

dimo333

dimo333

dimo333

dimo333

dimo333

dimo333

dimo333

dimo333

dimo333

## 10、软件安装：anaconda:

## 浏览器搜索 anaconda

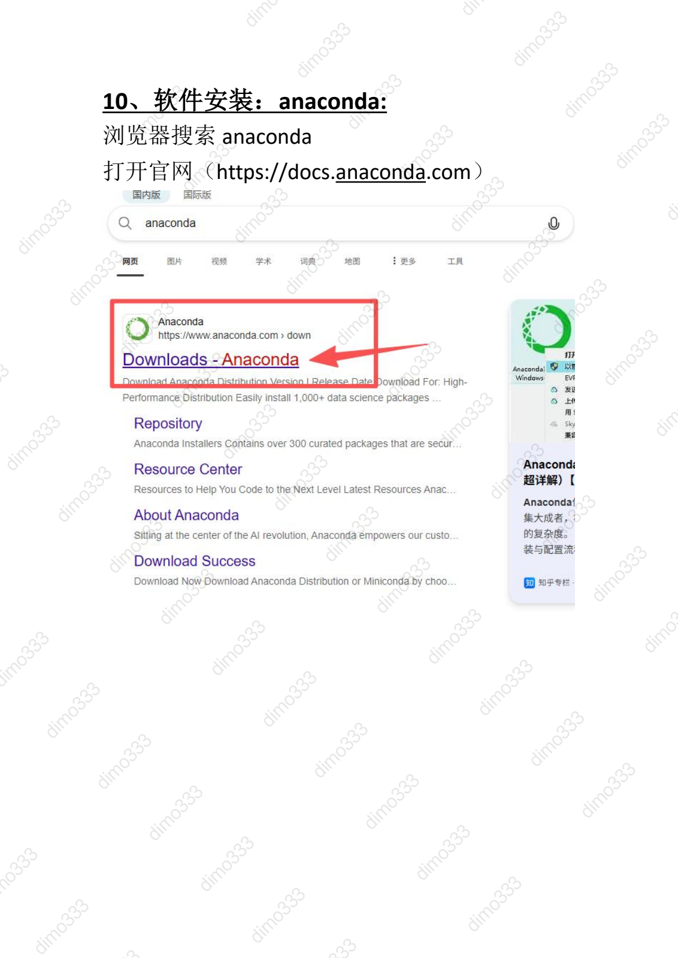
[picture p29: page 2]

## 打开官网（https://docs.anaconda.com）

dimo333

dimo333

dimo333

dimo333

dimo333

dimo333

dimo333

dimo333

dimo333

dimo333

dimo333

dimo333

dimo333

dimo333

dimo333

dimo333

dimo333

dimo333

dimo333

dimo333

dimo333

dimo333

dimo333

dimo333

dimo333

dimo333

dimo333

dimo333

dimo333

dimo333

dimo333

dimo333

dimo333

dimo333

dimo333

dimo333

dimo333

dimo333

dimo333

dimo333

dimo333

dimo333

dimo333

dimo333

dimo333

dimo333

dimo333

dimo333

dimo333

dimo333

## 点进去之后点这个 get started。

然后会需要你登录一个账户，没有就自己注册一
个

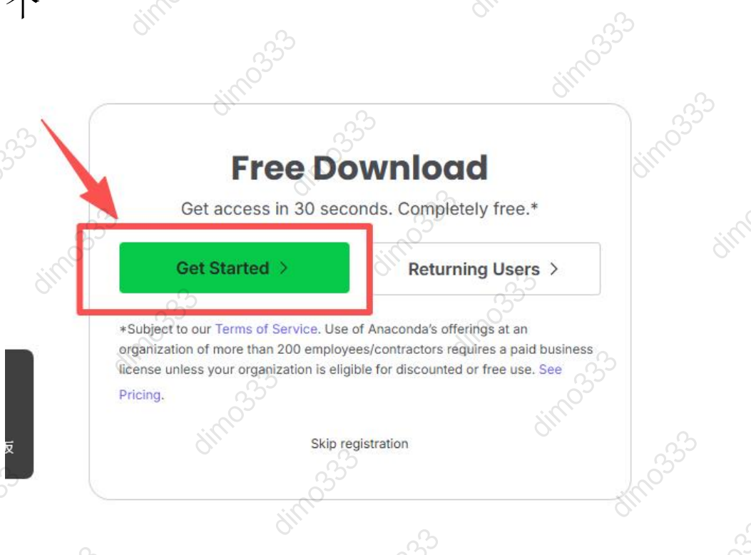
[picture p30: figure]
dimo333

dimo333

dimo333

dimo333

dimo333

dimo333

dimo333

dimo333

dimo333

dimo333

dimo333

dimo333

dimo333

dimo333

dimo333

dimo333

dimo333

dimo333

dimo333

dimo333

dimo333

dimo333

dimo333

dimo333

dimo333

dimo333

dimo333

dimo333

dimo333

dimo333

dimo333

dimo333

dimo333

dimo333

dimo333

dimo333

dimo333

dimo333

dimo333

跳转出来的界面，随便下载一个都可以，下载你
对应电脑系统的版本：

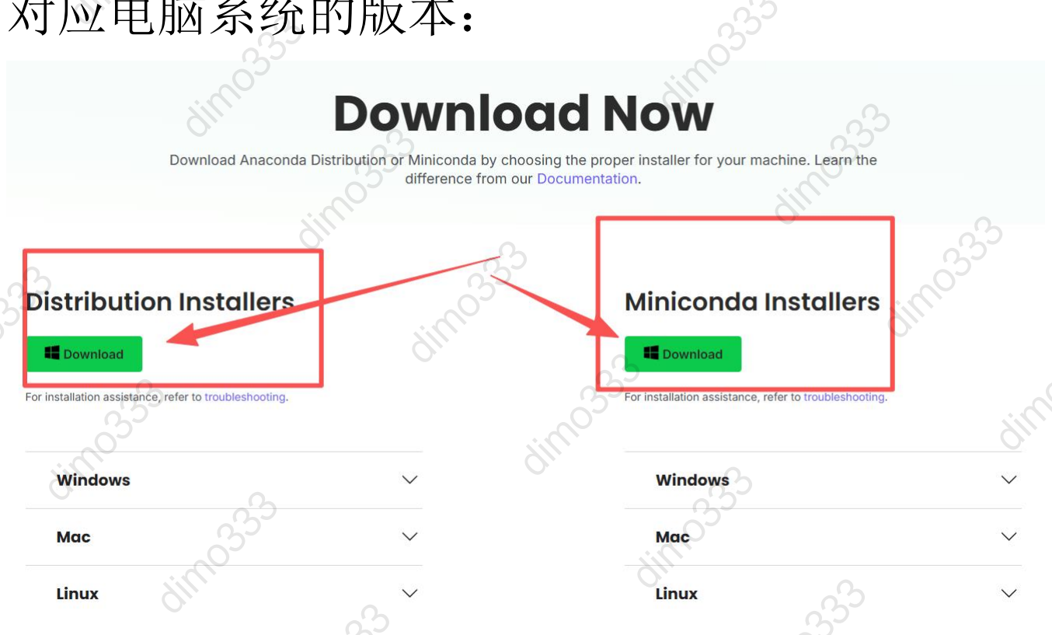
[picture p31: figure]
dimo333

自己找个文件夹安装就行

dimo333

dimo333

dimo333

dimo333

dimo333

dimo333

dimo333

dimo333

dimo333

dimo333

dimo333

dimo333

dimo333

dimo333

dimo333

dimo333

dimo333

dimo333

dimo333

dimo333

dimo333

dimo333

dimo333

dimo333

dimo333

dimo333

dimo333

dimo333

dimo333

dimo333

dimo333

dimo333

dimo333

dimo333

dimo333

dimo333

dimo333

dimo333

dimo333

dimo333

dimo333

接下来要把anaconda添加进电脑的环境变量里，
否则后续使用 vscode 时即便环境成功切换，

## vscode 也无法正常执行 conda 的指令。

打开电脑的设置搜索环境，选择编辑系统环境变
量:

dimo333

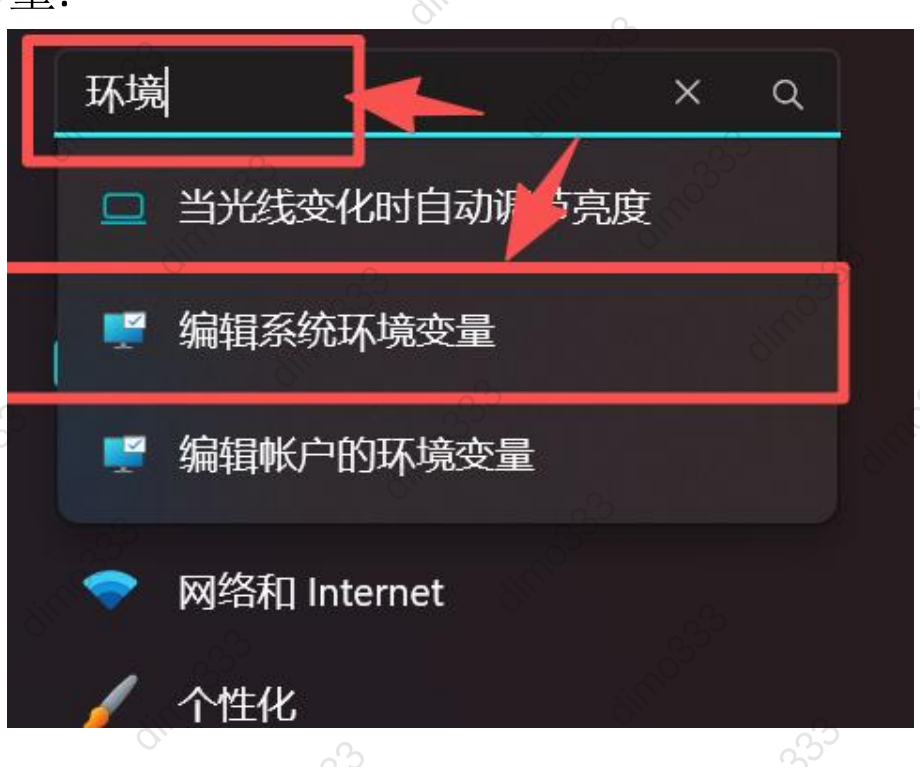
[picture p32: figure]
dimo333

dimo333

dimo333

dimo333

dimo333

dimo333

dimo333

dimo333

dimo333

dimo333

dimo333

dimo333

dimo333

dimo333

dimo333

dimo333

dimo333

dimo333

dimo333

dimo333

dimo333

dimo333

dimo333

dimo333

dimo333

dimo333

dimo333

dimo333

dimo333

dimo333

dimo333

dimo333

dimo333

dimo333

dimo333

dimo333

dimo333

dimo333

dimo333

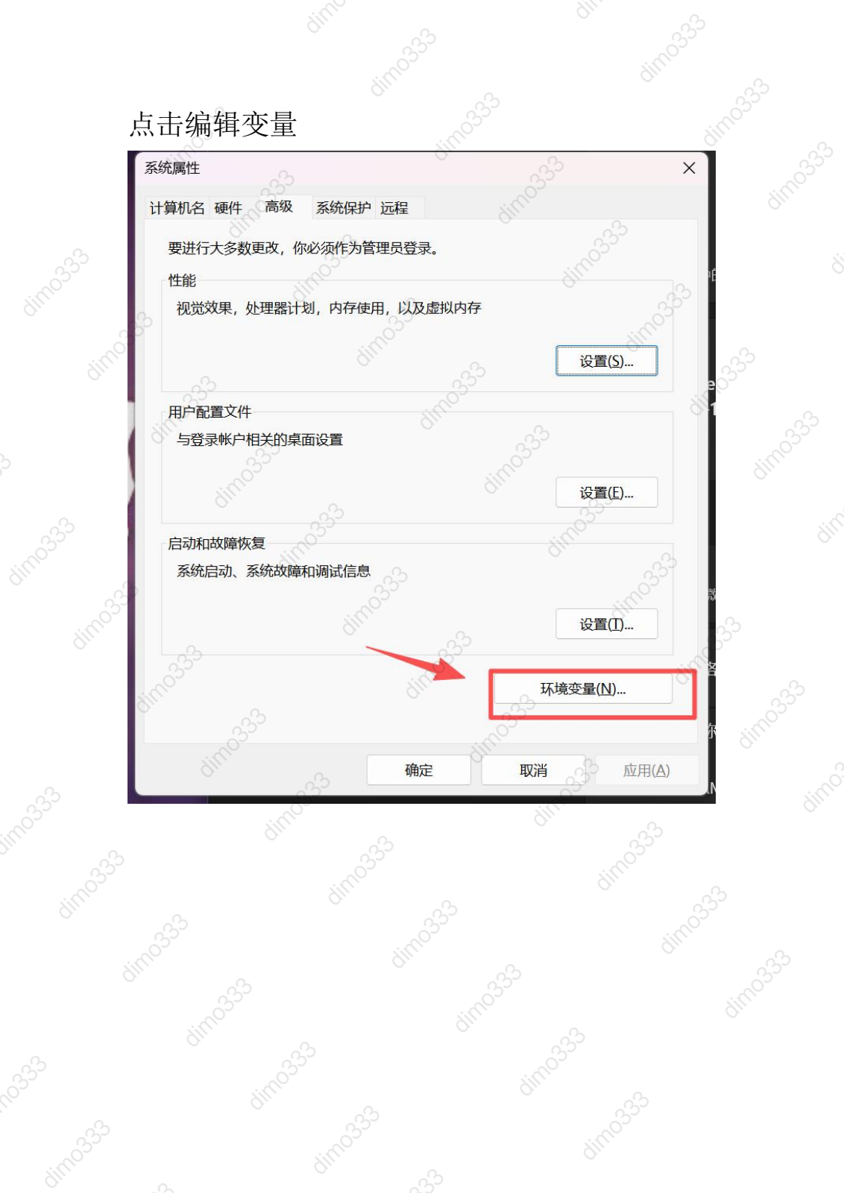
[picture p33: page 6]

点击编辑变量

dimo333

dimo333

dimo333

dimo333

dimo333

dimo333

dimo333

dimo333

dimo333

dimo333

dimo333

dimo333

dimo333

dimo333

dimo333

dimo333

dimo333

dimo333

dimo333

dimo333

dimo333

dimo333

dimo333

dimo333

dimo333

dimo333

dimo333

dimo333

dimo333

dimo333

dimo333

dimo333

dimo333

dimo333

dimo333

dimo333

dimo333

dimo333

dimo333

dimo333

dimo333

dimo333

dimo333

dimo333

dimo333

dimo333

dimo333

dimo333

dimo333

dimo333

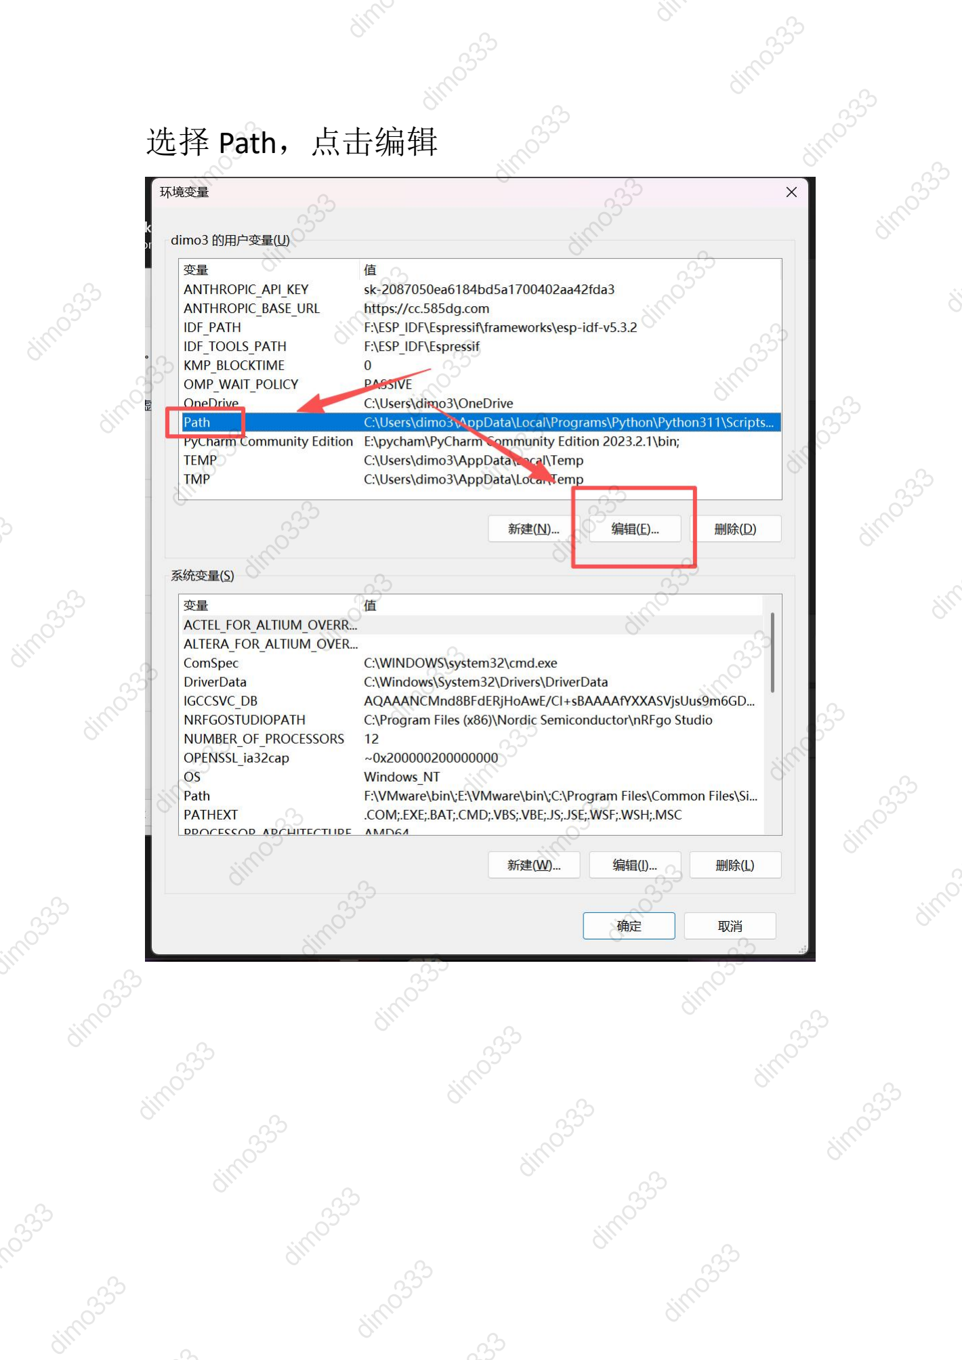
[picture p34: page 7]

选择 Path，点击编辑

dimo333

dimo333

dimo333

dimo333

dimo333

dimo333

dimo333

dimo333

dimo333

dimo333

dimo333

dimo333

dimo333

dimo333

dimo333

dimo333

dimo333

dimo333

dimo333

dimo333

dimo333

dimo333

dimo333

dimo333

dimo333

dimo333

dimo333

dimo333

dimo333

dimo333

dimo333

dimo333

dimo333

dimo333

dimo333

dimo333

dimo333

dimo333

dimo333

dimo333

dimo333

dimo333

dimo333

dimo333

dimo333

dimo333

dimo333

dimo333

dimo333

dimo333

点击右上角新建，下方出现一个需要填充的地方，

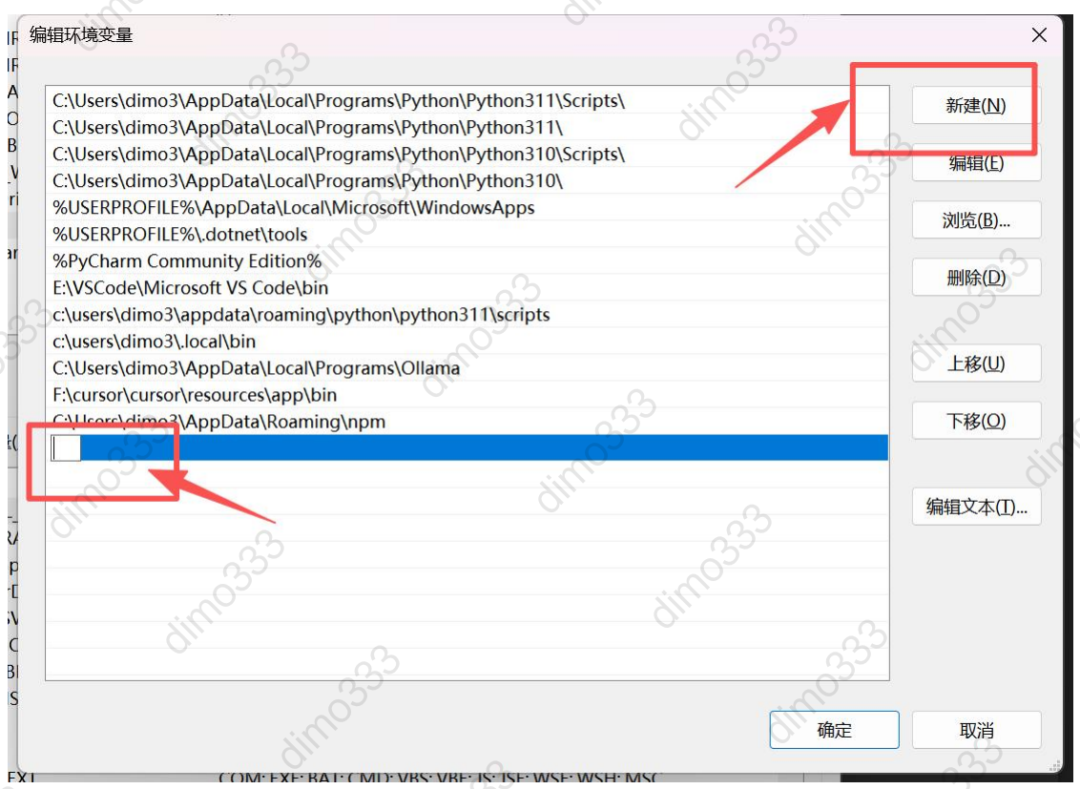
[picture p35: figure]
dimo333

dimo333

dimo333

dimo333

dimo333

dimo333

dimo333

dimo333

dimo333

dimo333

dimo333

dimo333

dimo333

dimo333

dimo333

dimo333

dimo333

dimo333

dimo333

dimo333

dimo333

dimo333

dimo333

dimo333

dimo333

dimo333

dimo333

dimo333

dimo333

dimo333

dimo333

dimo333

dimo333

dimo333

dimo333

dimo333

dimo333

dimo333

dimo333

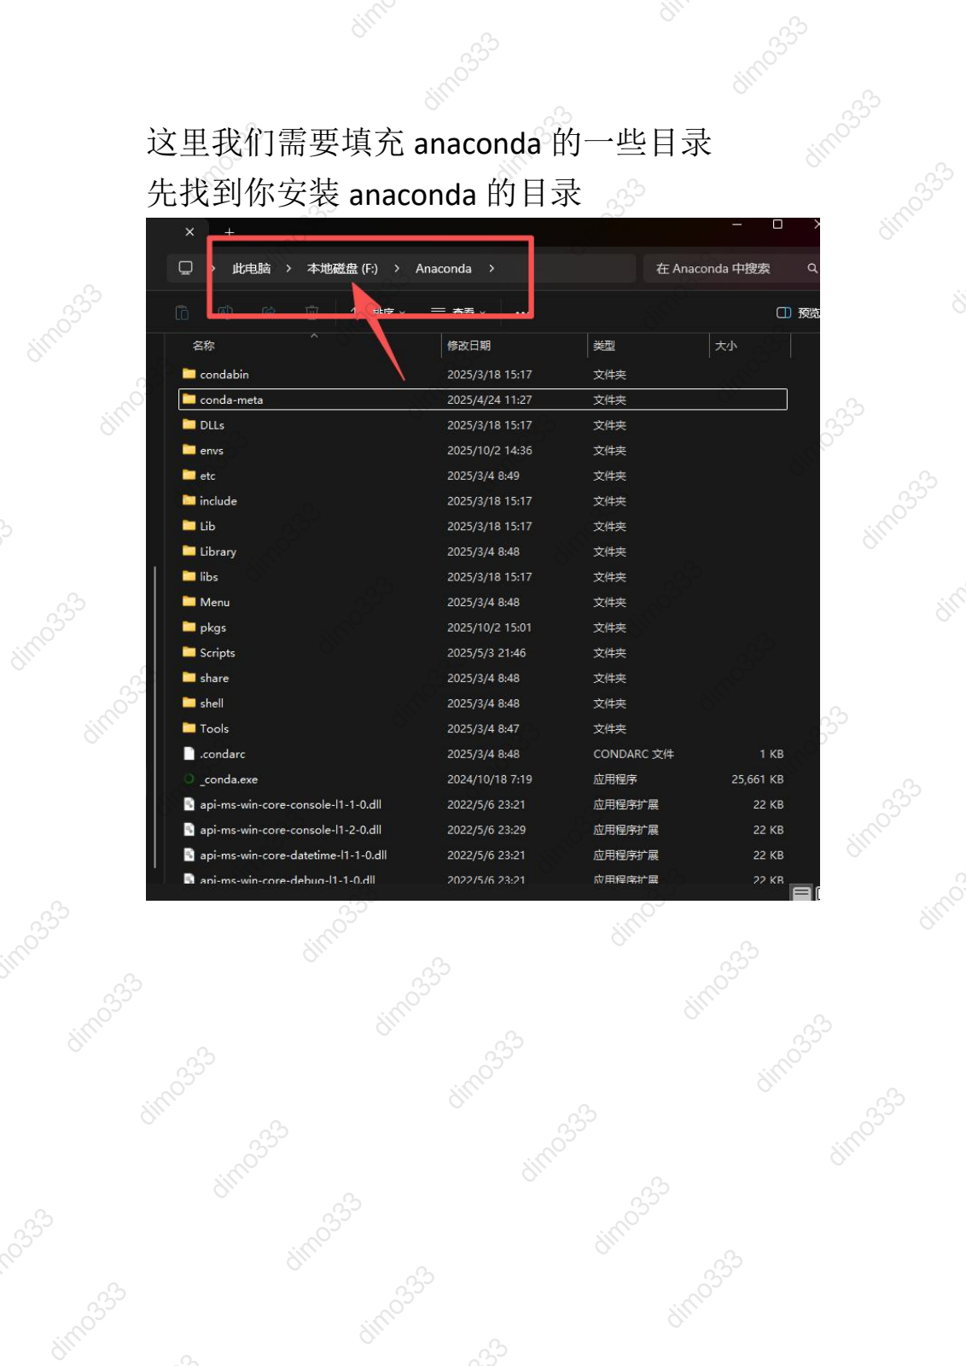
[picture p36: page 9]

这里我们需要填充 anaconda 的一些目录
先找到你安装 anaconda 的目录

dimo333

dimo333

dimo333

dimo333

dimo333

dimo333

dimo333

dimo333

dimo333

dimo333

dimo333

dimo333

dimo333

dimo333

dimo333

dimo333

dimo333

dimo333

dimo333

dimo333

dimo333

dimo333

dimo333

dimo333

dimo333

dimo333

dimo333

dimo333

dimo333

dimo333

dimo333

dimo333

dimo333

dimo333

dimo333

dimo333

dimo333

dimo333

dimo333

dimo333

dimo333

dimo333

dimo333

dimo333

dimo333

dimo333

dimo333

dimo333

dimo333

dimo333

找到以下五个：

## F:\Anaconda F:\Anaconda\Scripts F:\Anaconda\Library\bin

## F:\Anaconda\Library\usr\bin F:\Anaconda\Library\mingw-w64

我的印象中是只需要前面三个就好了，但是我在
写这部分教程，搜索资料的时候，看到有说还需
要添加以下目录的，保险起见，可以顺手添加上。
参考文章：

## （https://blog.csdn.net/lu8000/article/details/148

083990）

dimo333

dimo333

dimo333

dimo333

dimo333

dimo333

dimo333

dimo333

dimo333

dimo333

dimo333

dimo333

dimo333

dimo333

dimo333

dimo333

dimo333

dimo333

dimo333

dimo333

dimo333

dimo333

dimo333

dimo333

dimo333

dimo333

dimo333

dimo333

dimo333

dimo333

dimo333

dimo333

dimo333

dimo333

dimo333

dimo333

dimo333

dimo333

dimo333

dimo333

dimo333

dimo333

dimo333

dimo333

dimo333

dimo333

dimo333

dimo333

dimo333

dimo333

这里简单的添加了一个作为参考。
添加完点击确定

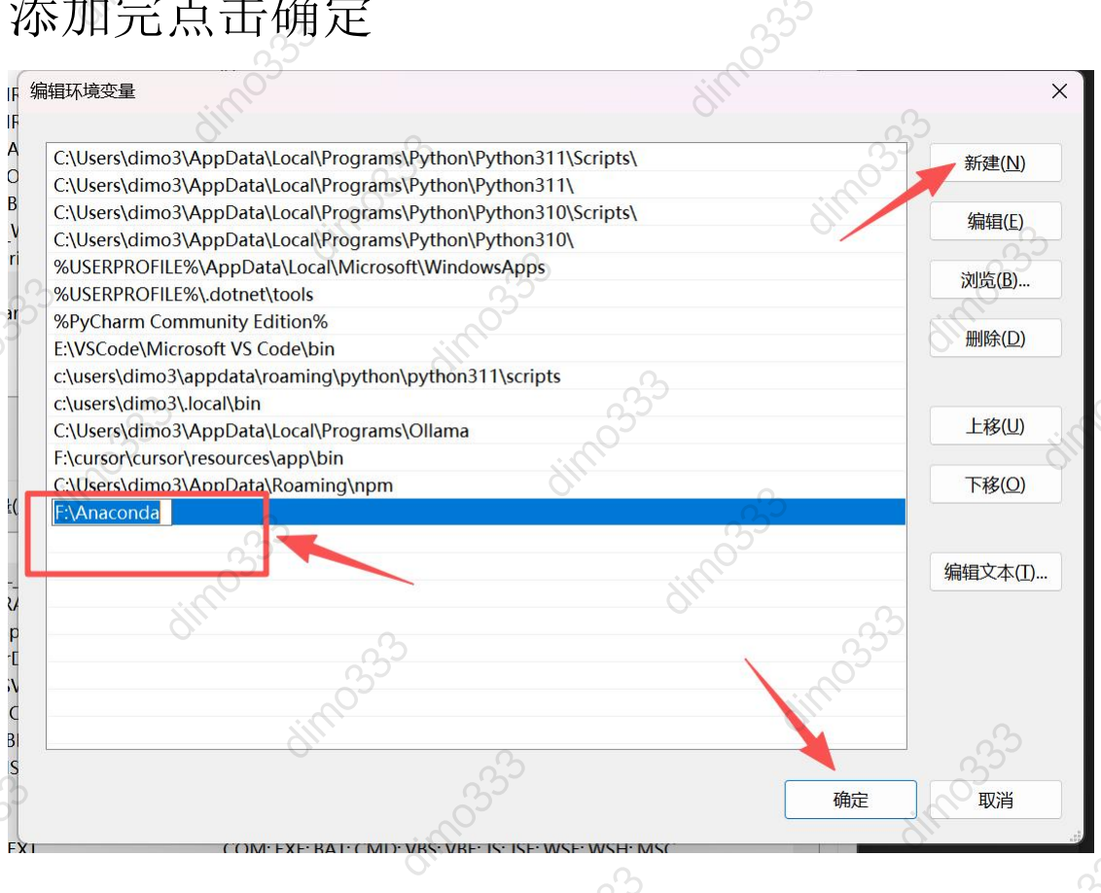
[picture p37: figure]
dimo333

dimo333

dimo333

dimo333

dimo333

dimo333

dimo333

dimo333

dimo333

dimo333

dimo333

dimo333

dimo333

dimo333

dimo333

dimo333

dimo333

dimo333

dimo333

dimo333

dimo333

dimo333

dimo333

dimo333

dimo333

dimo333

dimo333

dimo333

dimo333

dimo333

dimo333

dimo333

dimo333

dimo333

dimo333

dimo333

dimo333

dimo333

## 11、软件安装：git bash

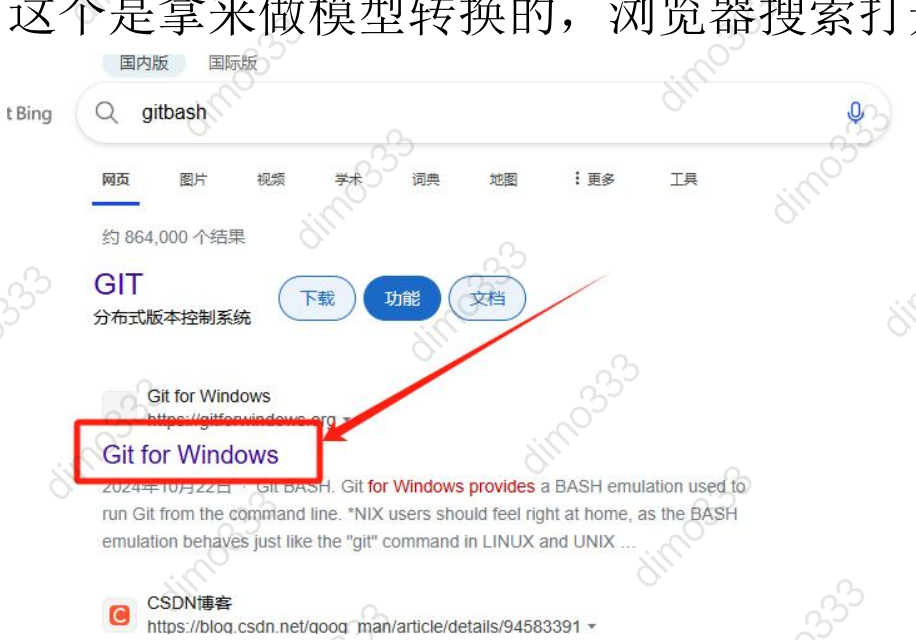
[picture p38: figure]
dimo333

这个是拿来做模型转换的，浏览器搜索打开

dimo333

dimo333

dimo333

dimo333

dimo333

dimo333

dimo333

dimo333

dimo333

dimo333

dimo333

dimo333

dimo333

dimo333

dimo333

dimo333

dimo333

dimo333

dimo333

dimo333

dimo333

dimo333

dimo333

dimo333

dimo333

dimo333

dimo333

dimo333

dimo333

dimo333

dimo333

dimo333

dimo333

dimo333

dimo333

dimo333

dimo333

dimo333

dimo333

dimo333

dimo333

dimo333

下载安装
有一个选项是添加路径到 vscode 里，还是添加
到系统环境里的，我忘记了，记得勾选上，等会
能省很多事

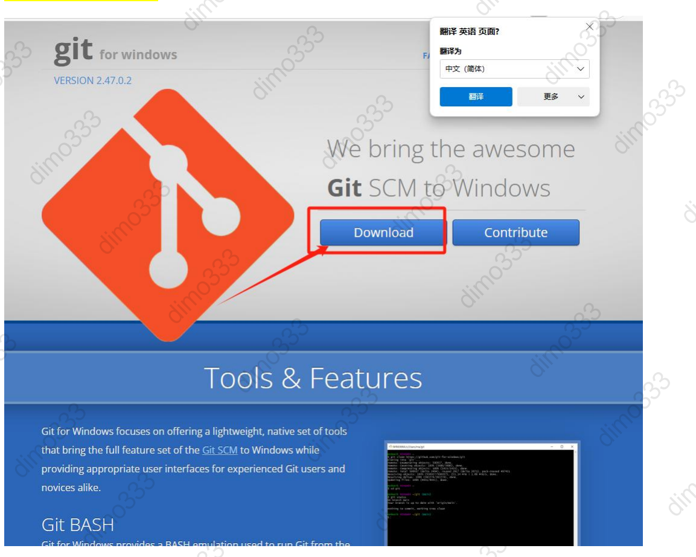
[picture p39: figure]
dimo333

dimo333

dimo333

dimo333

dimo333

dimo333

dimo333

dimo333

dimo333

dimo333

dimo333

dimo333

dimo333

dimo333

dimo333

dimo333

dimo333

dimo333

dimo333

dimo333

dimo333

dimo333

dimo333

dimo333

dimo333

dimo333

dimo333

dimo333

dimo333

dimo333

dimo333

dimo333

dimo333

dimo333

dimo333

## 12、环境搭建：anaconda

打开搜索框：

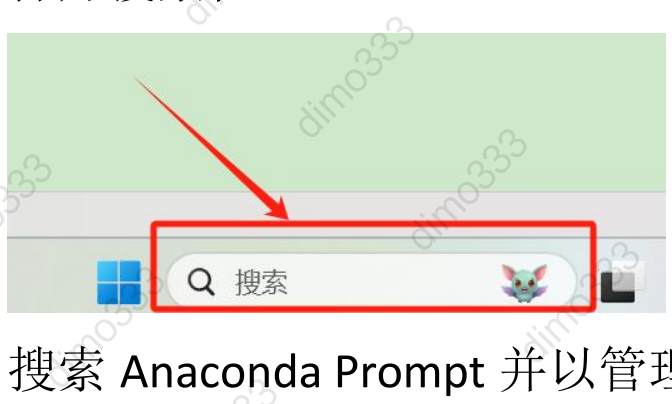
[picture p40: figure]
dimo333

## 搜索 Anaconda Prompt 并以管理员身份打开

输入命令：

## conda create -n dimo python=3.8

这一步是在创建环境，dimo 是这个环境的名字，
可以改成你喜欢的（如果你讨厌我的话..)

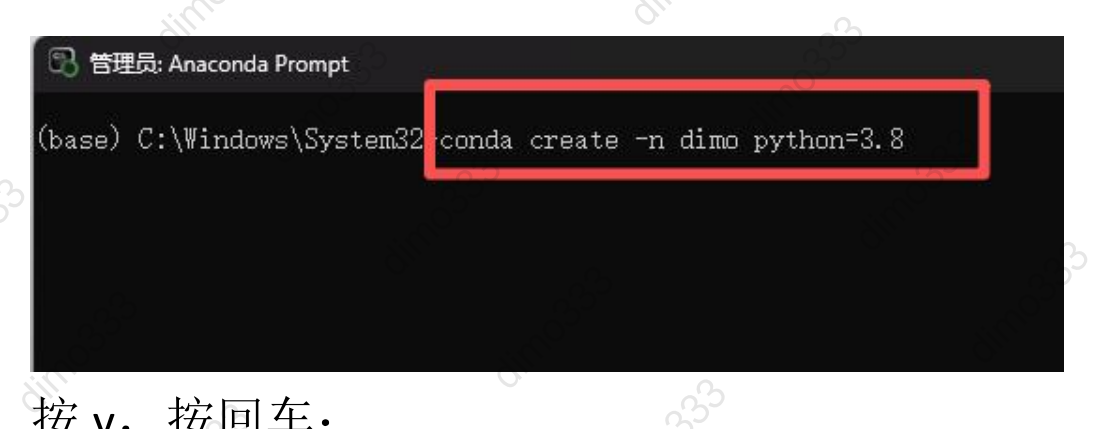
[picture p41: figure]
dimo333

按 y，按回车：

dimo333

dimo333

dimo333

dimo333

dimo333

dimo333

dimo333

dimo333

dimo333

dimo333

dimo333

dimo333

dimo333

dimo333

dimo333

dimo333

dimo333

dimo333

dimo333

dimo333

dimo333

dimo333

dimo333

dimo333

dimo333

dimo333

dimo333

dimo333

dimo333

dimo333

dimo333

dimo333

dimo333

dimo333

dimo333

dimo333

dimo333

dimo333

dimo333

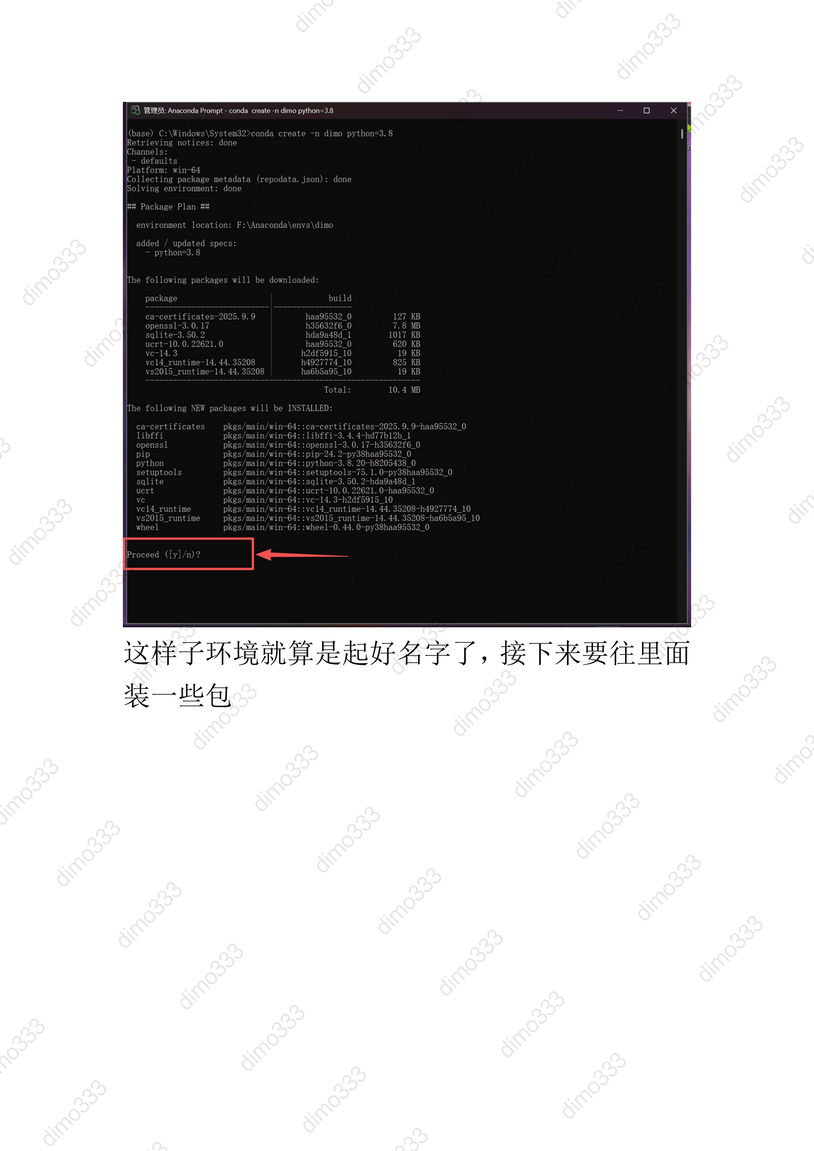
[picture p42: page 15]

这样子环境就算是起好名字了，接下来要往里面
装一些包

dimo333

dimo333

dimo333

dimo333

dimo333

dimo333

dimo333

dimo333

dimo333

dimo333

dimo333

dimo333

dimo333

dimo333

dimo333

dimo333

dimo333

dimo333

dimo333

dimo333

dimo333

dimo333

dimo333

dimo333

dimo333

dimo333

dimo333

dimo333

dimo333

dimo333

dimo333

dimo333

dimo333

dimo333

dimo333

dimo333

dimo333

dimo333

dimo333

dimo333

dimo333

dimo333

dimo333

dimo333

dimo333

dimo333

dimo333

dimo333

dimo333

dimo333

需要进入这个环境，才能装包
输入命令：

## conda activate dimo

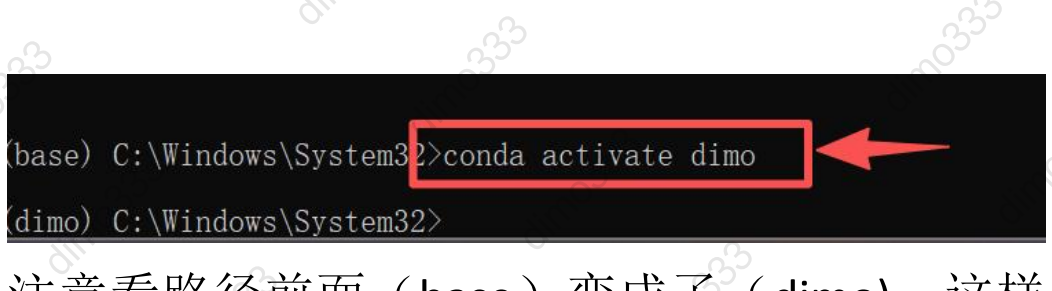
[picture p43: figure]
dimo333

注意看路径前面（base）变成了（dimo)，这样
就说明我们从基础环境进入到了我们刚刚创建
的 dimo 环境里

dimo333

dimo333

dimo333

dimo333

dimo333

dimo333

dimo333

dimo333

dimo333

dimo333

dimo333

dimo333

dimo333

dimo333

dimo333

dimo333

dimo333

dimo333

dimo333

dimo333

dimo333

dimo333

dimo333

dimo333

dimo333

dimo333

dimo333

dimo333

dimo333

dimo333

dimo333

dimo333

dimo333

dimo333

dimo333

dimo333

dimo333

dimo333

dimo333

dimo333

dimo333

dimo333

dimo333

dimo333

dimo333

dimo333

dimo333

接下来需要安装三个东西：

## tensorflow：

输入指令：

## conda install tensorflow==2.10.0

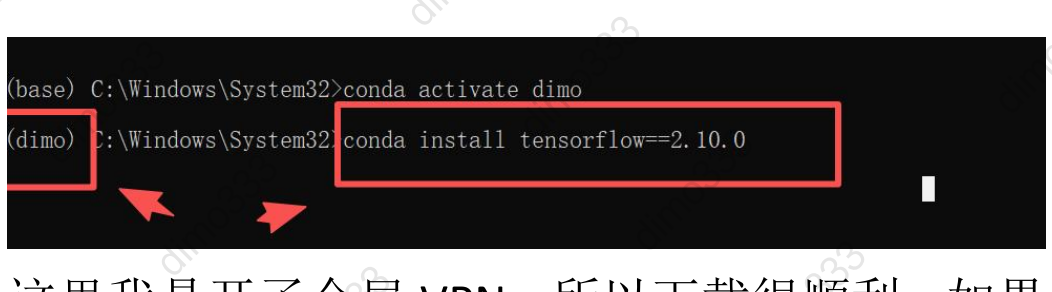
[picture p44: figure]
dimo333

这里我是开了全局 VPN，所以下载很顺利，如果
你下载失败了并且没有 VPN 的话，请使用清华源
或其它源。使用方法可以参考这篇文章：

## https://blog.csdn.net/ytusdc/article/details/89469

161

dimo333

dimo333

dimo333

dimo333

dimo333

dimo333

dimo333

dimo333

dimo333

dimo333

dimo333

dimo333

dimo333

dimo333

dimo333

dimo333

dimo333

dimo333

dimo333

dimo333

dimo333

dimo333

dimo333

dimo333

dimo333

dimo333

dimo333

dimo333

dimo333

dimo333

dimo333

dimo333

dimo333

dimo333

dimo333

dimo333

dimo333

dimo333

dimo333

dimo333

dimo333

dimo333

dimo333

dimo333

dimo333

dimo333

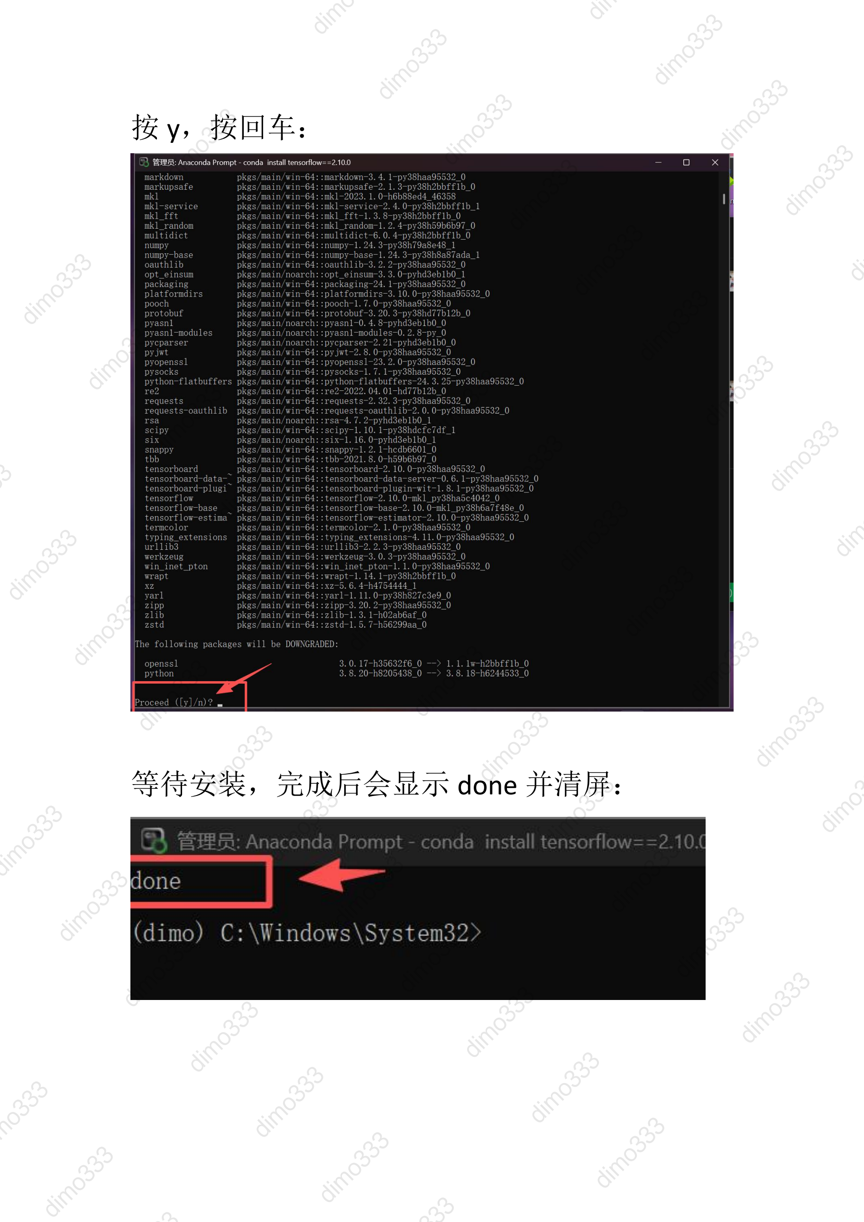
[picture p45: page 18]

按 y，按回车：

等待安装，完成后会显示 done 并清屏：

dimo333

dimo333

dimo333

dimo333

dimo333

dimo333

dimo333

dimo333

dimo333

dimo333

dimo333

dimo333

dimo333

dimo333

dimo333

dimo333

dimo333

dimo333

dimo333

dimo333

dimo333

dimo333

dimo333

dimo333

dimo333

dimo333

dimo333

dimo333

dimo333

dimo333

dimo333

dimo333

dimo333

dimo333

dimo333

dimo333

dimo333

dimo333

dimo333

dimo333

dimo333

dimo333

dimo333

dimo333

dimo333

dimo333

dimo333

dimo333

dimo333

dimo333

## pandas：

输入指令：

## conda install pandas

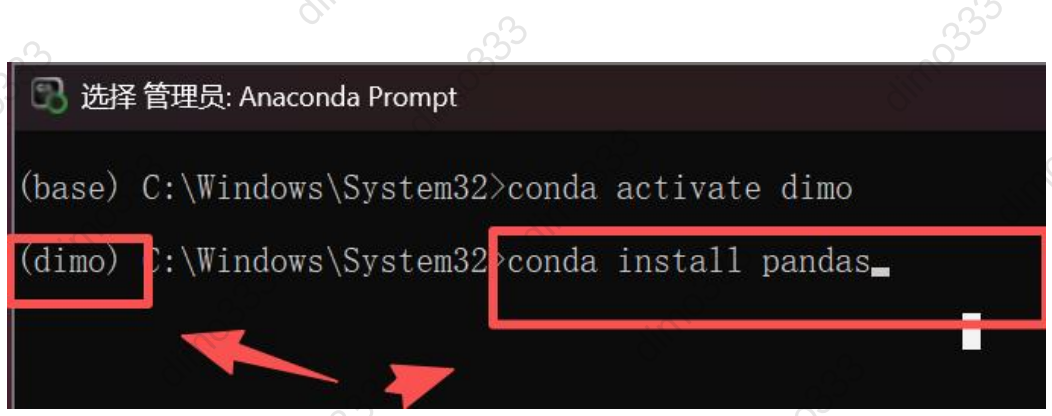
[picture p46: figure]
dimo333

dimo333

dimo333

dimo333

dimo333

dimo333

dimo333

dimo333

dimo333

dimo333

dimo333

dimo333

dimo333

dimo333

dimo333

dimo333

dimo333

dimo333

dimo333

dimo333

dimo333

dimo333

dimo333

dimo333

dimo333

dimo333

dimo333

dimo333

dimo333

dimo333

dimo333

dimo333

dimo333

dimo333

dimo333

dimo333

dimo333

dimo333

dimo333

dimo333

dimo333

dimo333

dimo333

dimo333

dimo333

dimo333

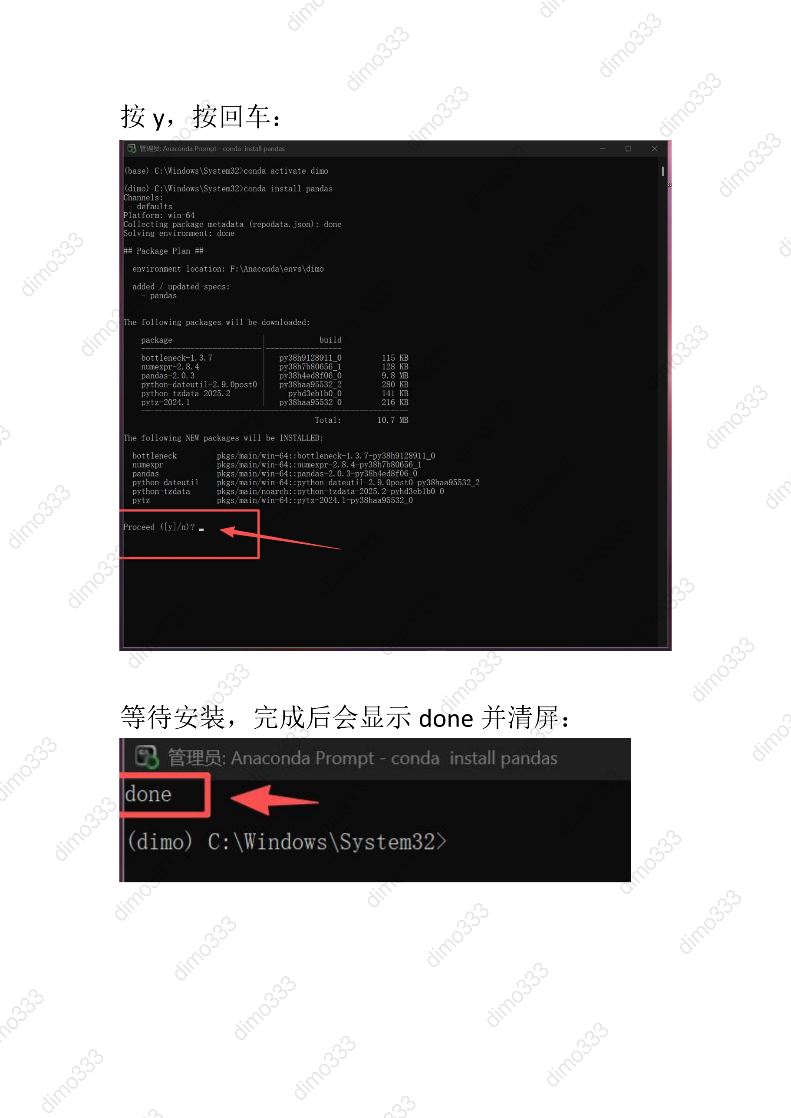
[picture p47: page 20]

按 y，按回车：

等待安装，完成后会显示 done 并清屏：

dimo333

dimo333

dimo333

dimo333

dimo333

dimo333

dimo333

dimo333

dimo333

dimo333

dimo333

dimo333

dimo333

dimo333

dimo333

dimo333

dimo333

dimo333

dimo333

dimo333

dimo333

dimo333

dimo333

dimo333

dimo333

dimo333

dimo333

dimo333

dimo333

dimo333

dimo333

dimo333

dimo333

dimo333

dimo333

dimo333

dimo333

dimo333

dimo333

dimo333

dimo333

dimo333

dimo333

dimo333

dimo333

dimo333

dimo333

dimo333

dimo333

dimo333

## pyserial：

## conda install pyserial

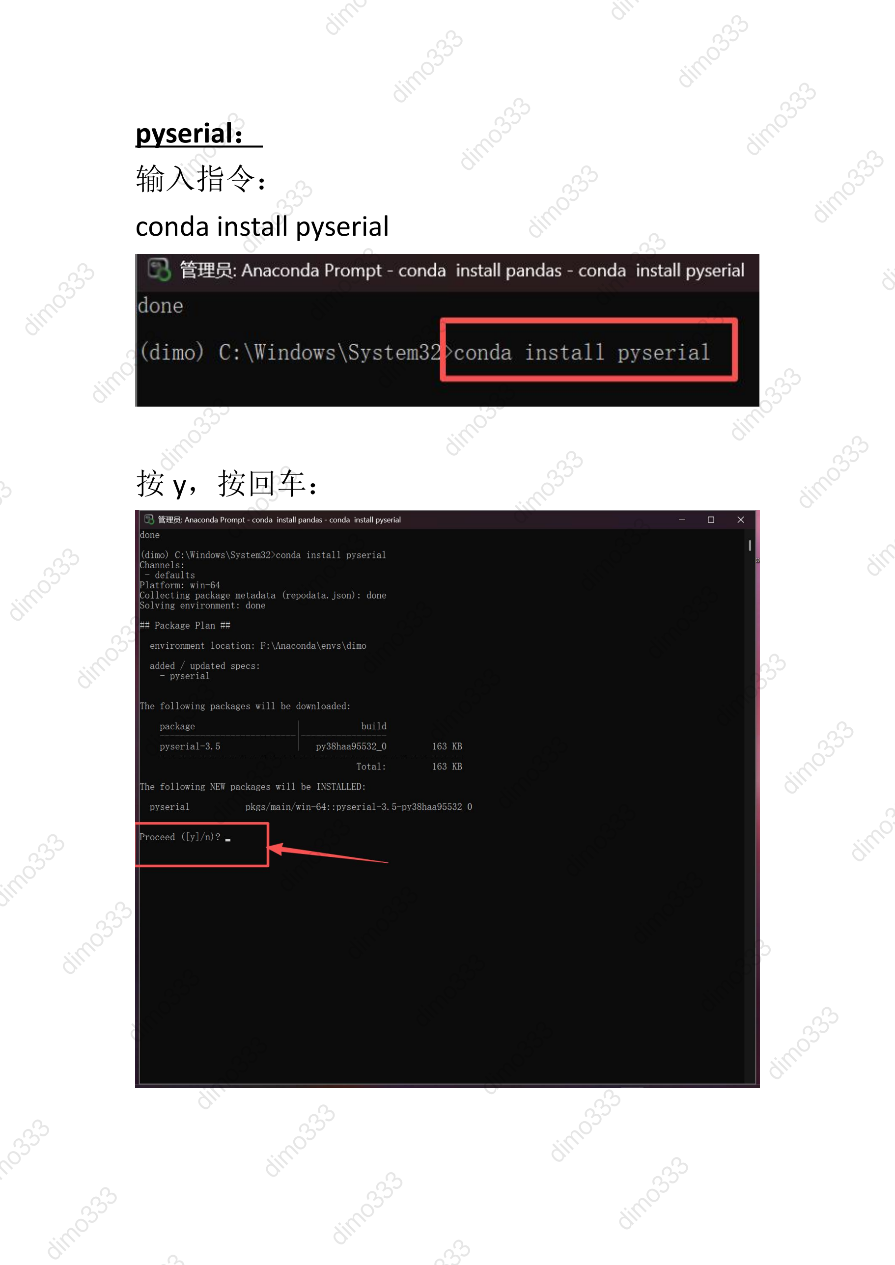
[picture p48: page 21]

输入指令：

按 y，按回车：

dimo333

dimo333

dimo333

dimo333

dimo333

dimo333

dimo333

dimo333

dimo333

dimo333

dimo333

dimo333

dimo333

dimo333

dimo333

dimo333

dimo333

dimo333

dimo333

dimo333

dimo333

dimo333

dimo333

dimo333

dimo333

dimo333

dimo333

dimo333

dimo333

dimo333

dimo333

dimo333

dimo333

dimo333

dimo333

dimo333

dimo333

dimo333

dimo333

dimo333

dimo333

dimo333

dimo333

dimo333

dimo333

dimo333

dimo333

dimo333

dimo333

dimo333

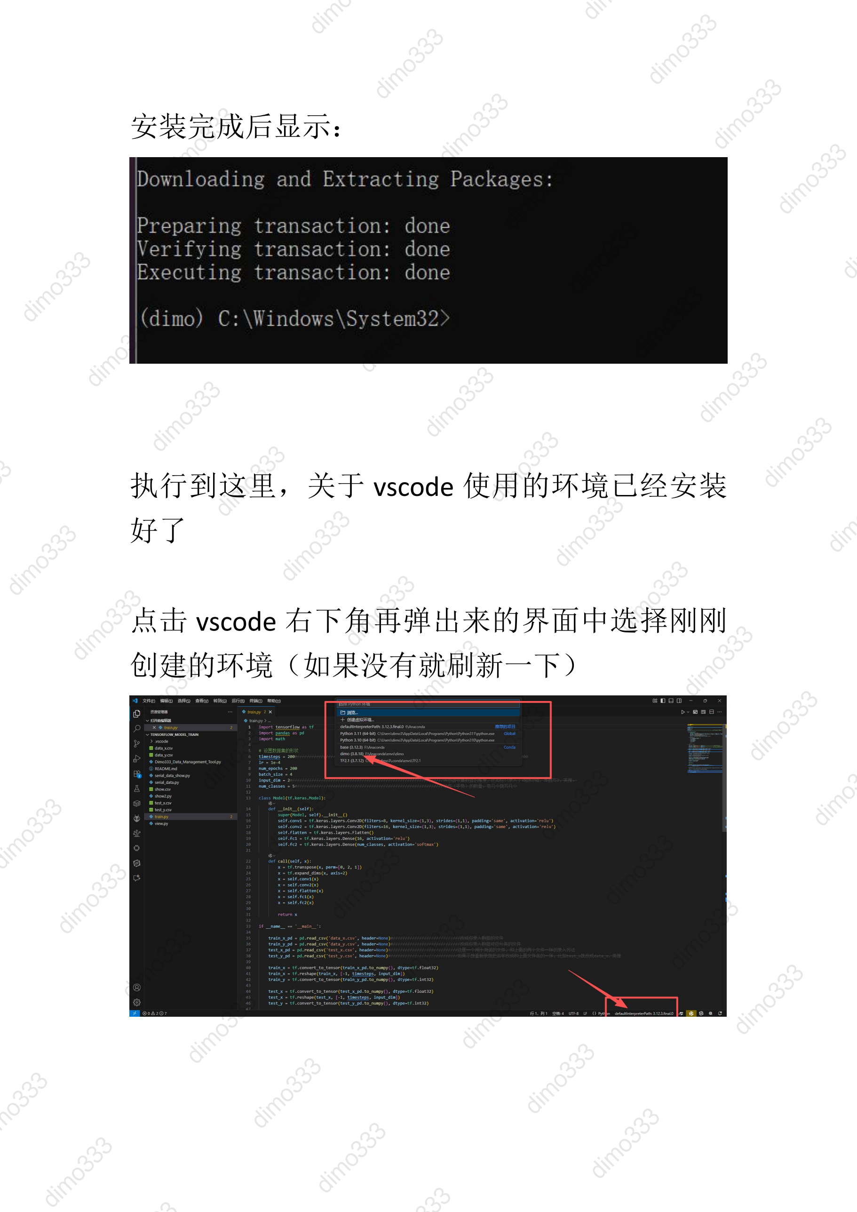
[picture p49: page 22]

安装完成后显示：

执行到这里，关于 vscode 使用的环境已经安装
好了

点击 vscode 右下角再弹出来的界面中选择刚刚
创建的环境（如果没有就刷新一下）

dimo333

dimo333

dimo333

dimo333

dimo333

dimo333

dimo333

dimo333

dimo333

dimo333

dimo333

dimo333

dimo333

dimo333

dimo333

dimo333

dimo333

dimo333

dimo333

dimo333

dimo333

dimo333

dimo333

dimo333

dimo333

dimo333

dimo333

dimo333

dimo333

dimo333

dimo333

dimo333

dimo333

dimo333

dimo333

dimo333

dimo333

dimo333

dimo333

dimo333

dimo333

dimo333

dimo333

dimo333

dimo333

dimo333

dimo333

dimo333

dimo333

dimo333

当右下角显示的是你刚刚创建的环境就 ok 了

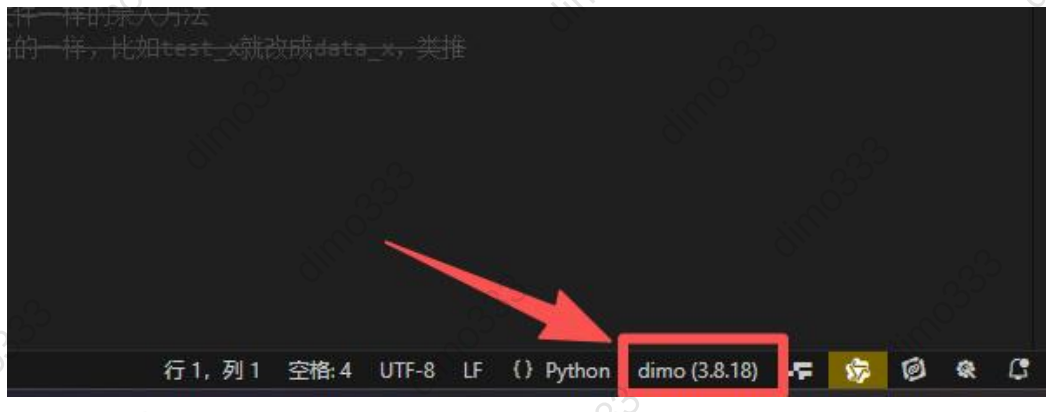
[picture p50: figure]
dimo333

如果你执行到这里，关于进阶部分的软件安装、
环境搭建就结束了，你可以前往下一章

## Use_Process_advanced.docs

开始你的探索了

dimo333

dimo333

dimo333

dimo333

dimo333

dimo333

dimo333

dimo333

dimo333

dimo333

dimo333

dimo333

dimo333

dimo333

dimo333

dimo333

dimo333

dimo333

dimo333

dimo333

dimo333

dimo333

dimo333

dimo333

dimo333

dimo333

dimo333

dimo333

dimo333

dimo333

dimo333

dimo333

dimo333

dimo333

dimo333

dimo333

dimo333

dimo333

dimo333

dimo333

dimo333

dimo333

dimo333

dimo333

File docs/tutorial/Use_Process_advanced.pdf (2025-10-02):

以下部分教程会异常的难，如果你畏惧了，
可以在看完这一段话后开始放弃。
开始前，请确保你成功运行并将烧录至魔杖，
否则后续执行时可能会出现问题。

13、打开 vscode，点击左上角 文件->打开文件夹：

dimo333

dimo333

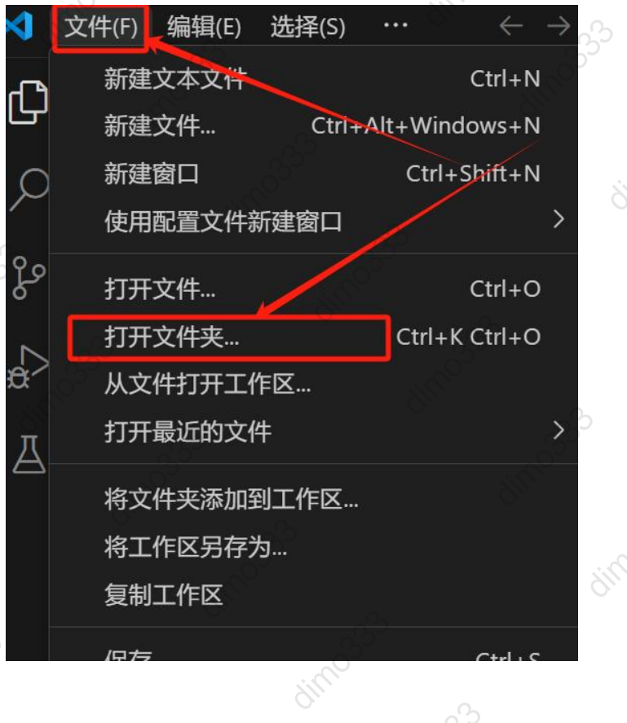
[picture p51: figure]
dimo333

dimo333

dimo333

dimo333

dimo333

dimo333

dimo333

dimo333

dimo333

dimo333

dimo333

dimo333

dimo333

dimo333

dimo333

dimo333

dimo333

dimo333

dimo333

dimo333

dimo333

dimo333

dimo333

dimo333

dimo333

dimo333

dimo333

dimo333

dimo333

dimo333

dimo333

dimo333

dimo333

dimo333

dimo333

dimo333

dimo333

dimo333

dimo333

dimo333

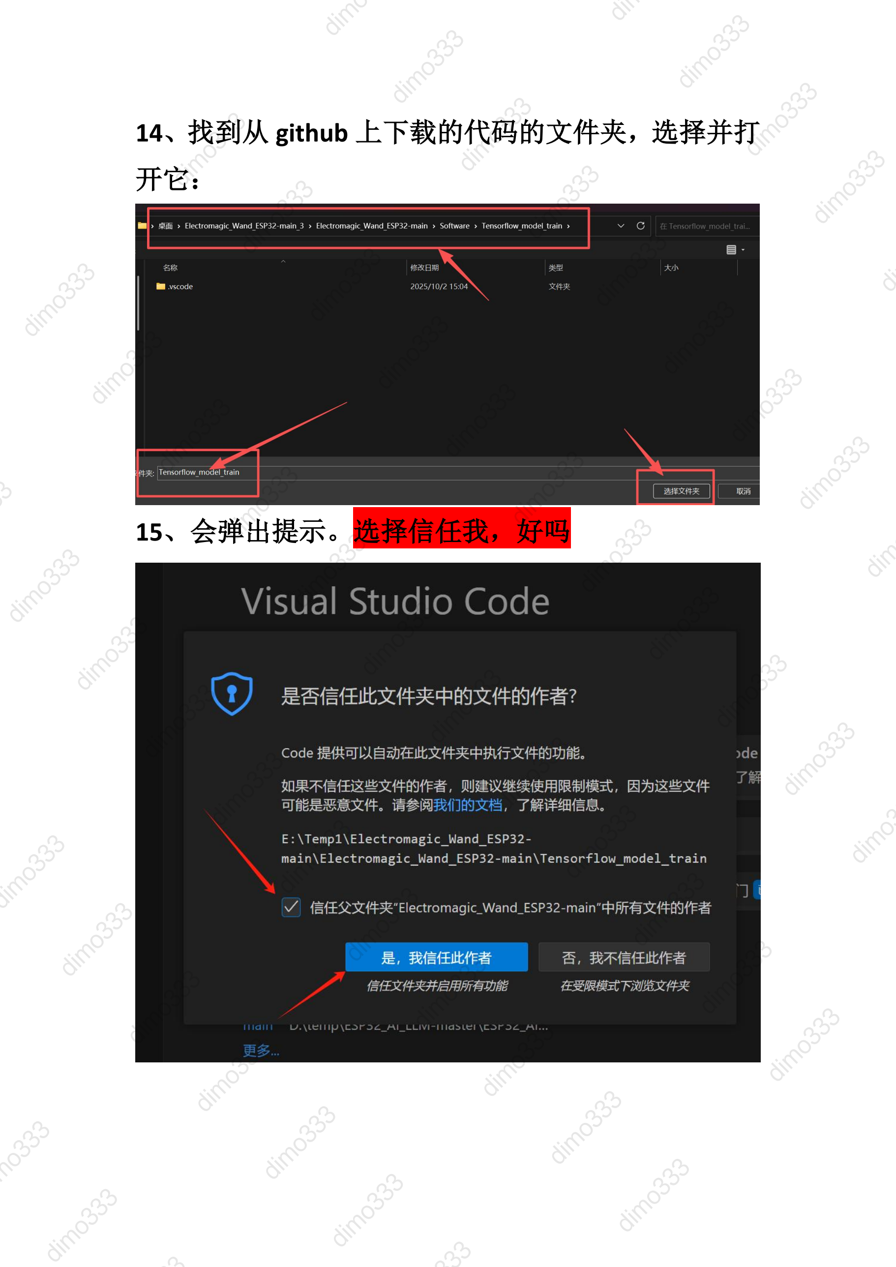
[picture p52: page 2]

14、找到从 github 上下载的代码的文件夹，选择并打

开它：

15、会弹出提示。选择信任我，好吗

dimo333

dimo333

dimo333

dimo333

dimo333

dimo333

dimo333

dimo333

dimo333

dimo333

dimo333

dimo333

dimo333

dimo333

dimo333

dimo333

dimo333

dimo333

dimo333

dimo333

dimo333

dimo333

dimo333

dimo333

dimo333

dimo333

dimo333

dimo333

dimo333

dimo333

dimo333

dimo333

dimo333

dimo333

dimo333

dimo333

dimo333

dimo333

dimo333

dimo333

dimo333

dimo333

dimo333

dimo333

dimo333

dimo333

dimo333

dimo333

dimo333

dimo333

## 16、左边选择 serial_data 文件，修改你 esp 连上电

脑的串口号，然后选择一个存放录入数据的 csv 文件

（ 这 里 如 果 不 想 用 我 的 数 据 ， 可 以 左 边 打 开

## date_x.csv 和 data_y.csv 删除里面的数据），然后在

label 的方框里填写需要录制的动作序号（这里我以动

## 作 0 举例，并且已经清除了 date_x.csv 和 data_y.csv

的所有数据）。
（这一步记得关闭 arduinoIDE，避免串口被占用）

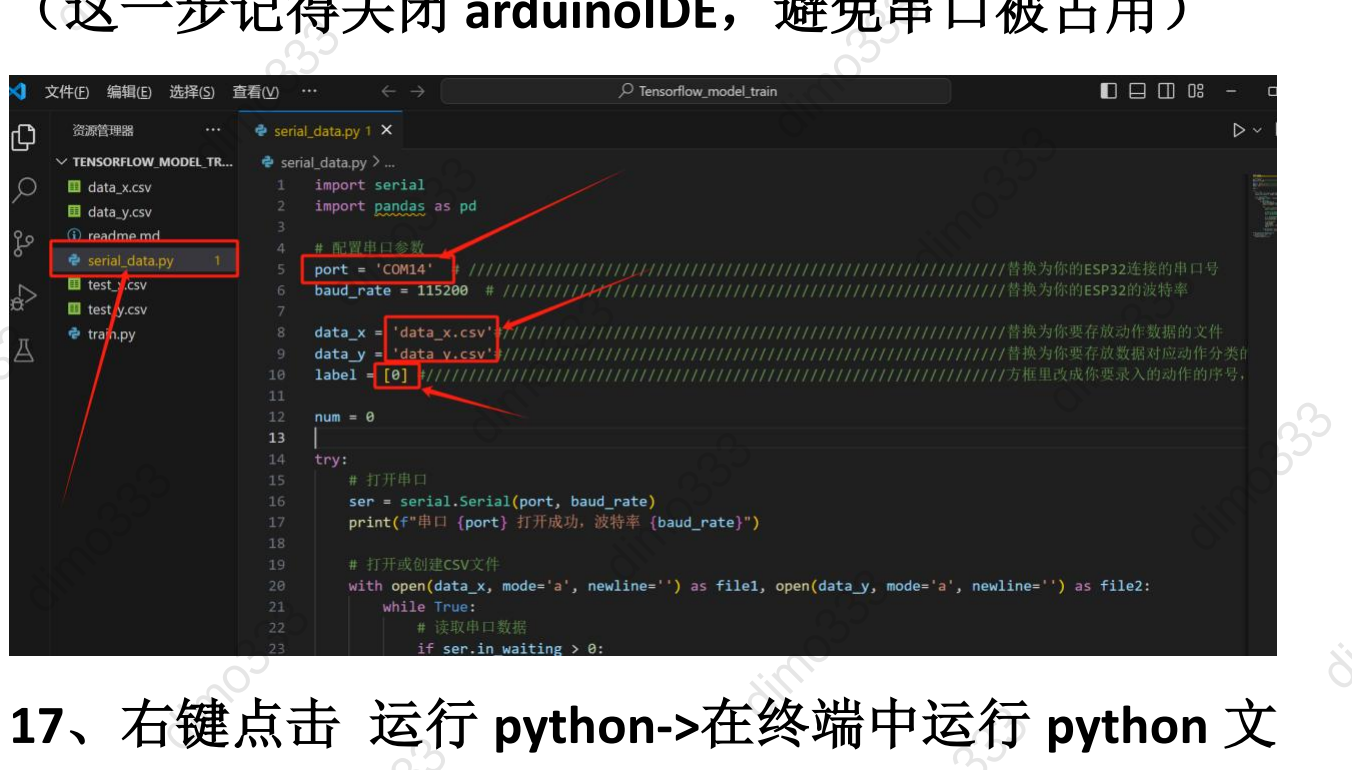
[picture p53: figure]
dimo333

## 17、右键点击 运行 python->在终端中运行 python 文

件

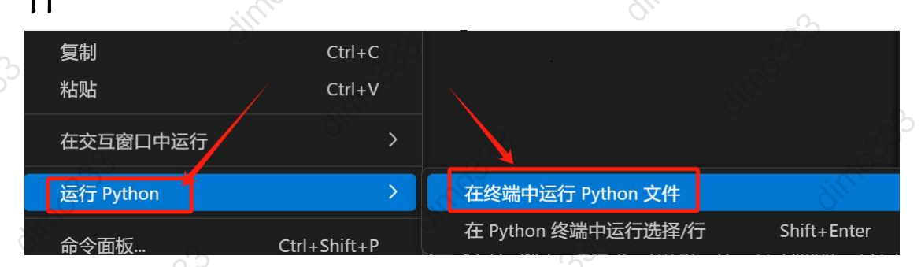
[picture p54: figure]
dimo333

dimo333

dimo333

dimo333

dimo333

dimo333

dimo333

dimo333

dimo333

dimo333

dimo333

dimo333

dimo333

dimo333

dimo333

dimo333

dimo333

dimo333

dimo333

dimo333

dimo333

dimo333

dimo333

dimo333

dimo333

dimo333

dimo333

dimo333

dimo333

dimo333

dimo333

dimo333

dimo333

dimo333

dimo333

dimo333

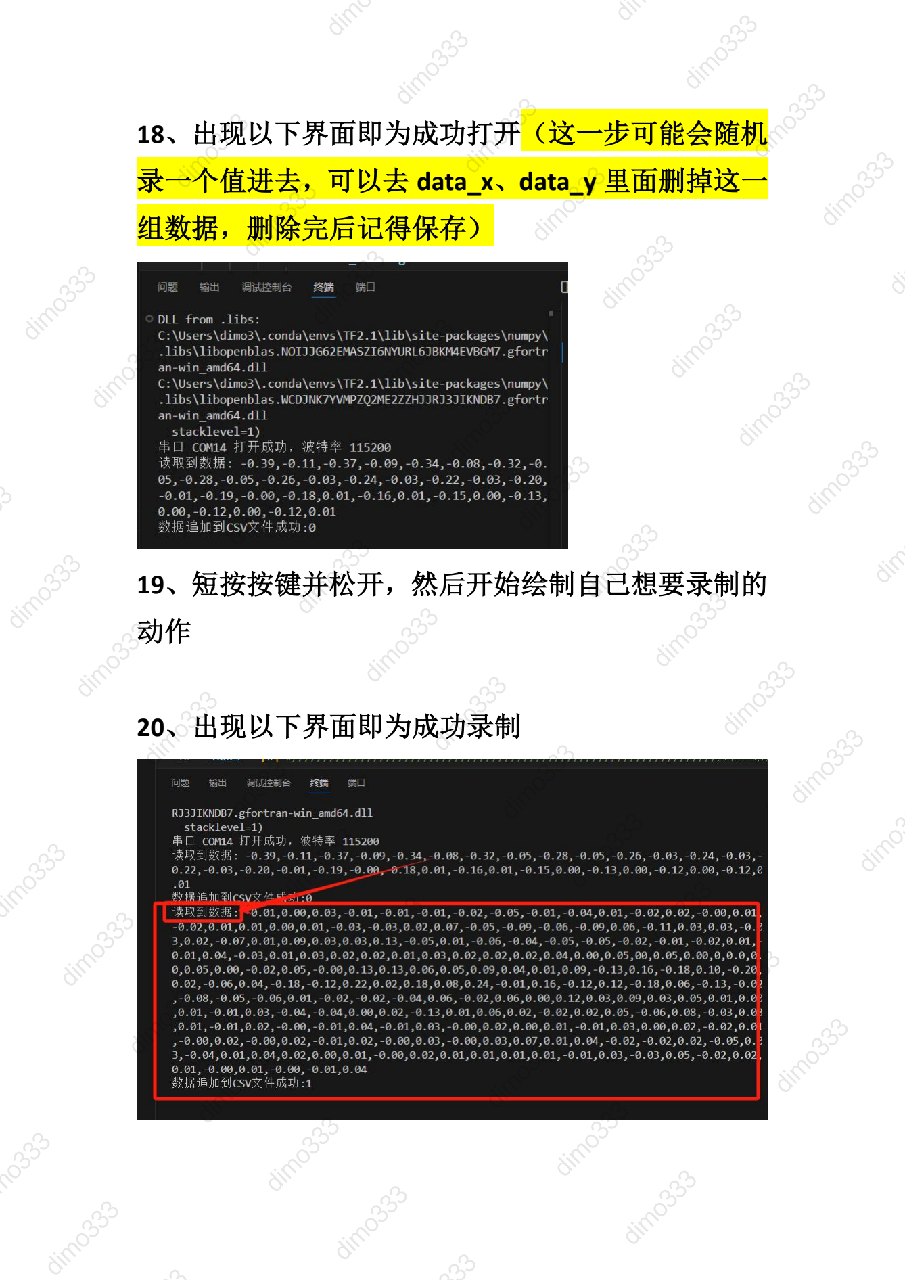
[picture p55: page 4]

18、出现以下界面即为成功打开（这一步可能会随机
录一个值进去，可以去 data_x、data_y 里面删掉这一

组数据，删除完后记得保存）

19、短按按键并松开，然后开始绘制自己想要录制的

动作

20、出现以下界面即为成功录制

dimo333

dimo333

dimo333

dimo333

dimo333

dimo333

dimo333

dimo333

dimo333

dimo333

dimo333

dimo333

dimo333

dimo333

dimo333

dimo333

dimo333

dimo333

dimo333

dimo333

dimo333

dimo333

dimo333

dimo333

dimo333

dimo333

dimo333

dimo333

dimo333

dimo333

dimo333

dimo333

dimo333

dimo333

dimo333

dimo333

dimo333

dimo333

dimo333

dimo333

dimo333

dimo333

dimo333

dimo333

dimo333

dimo333

dimo333

dimo333

dimo333

dimo333

21、动作 0 录制完成后，关闭当前终端

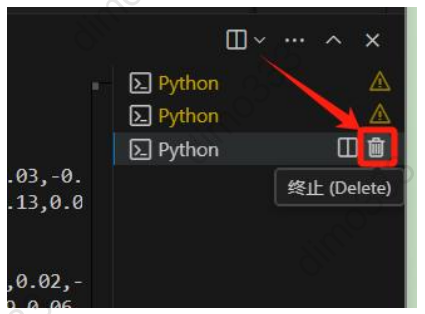
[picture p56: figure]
dimo333

22、如果需要继续录制动作 1，请返回第 16 步继续操

作
23、如果需要训练当前录制完成的动作模型文件，左
边文件中选择 train 文件，修改代码当中 input_dim 参 数（如果你只使用了两个轴，比如 x 轴、z 轴，这里 就需要填写 2），修改岗前代码当中 num_classes 参数 （几个手势就写几，1 个就写 1，2 个就写 2）

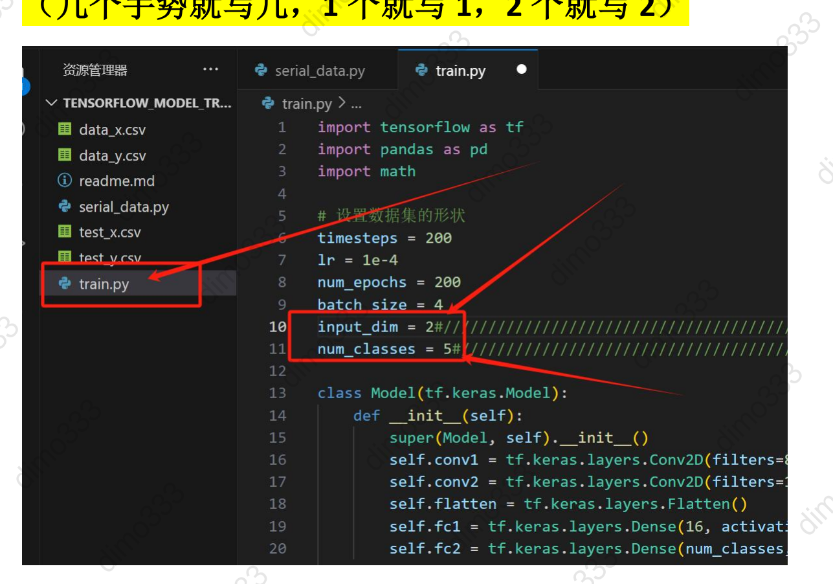
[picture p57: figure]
dimo333

dimo333

dimo333

dimo333

dimo333

dimo333

dimo333

dimo333

dimo333

dimo333

dimo333

dimo333

dimo333

dimo333

dimo333

dimo333

dimo333

dimo333

dimo333

dimo333

dimo333

dimo333

dimo333

dimo333

dimo333

dimo333

dimo333

dimo333

dimo333

dimo333

dimo333

dimo333

dimo333

dimo333

dimo333

24、往下找到文件定义部分，如果不需要 test_x、test_y

## 可以替换成 data_x、data_y（亦或把 data_x、data_y

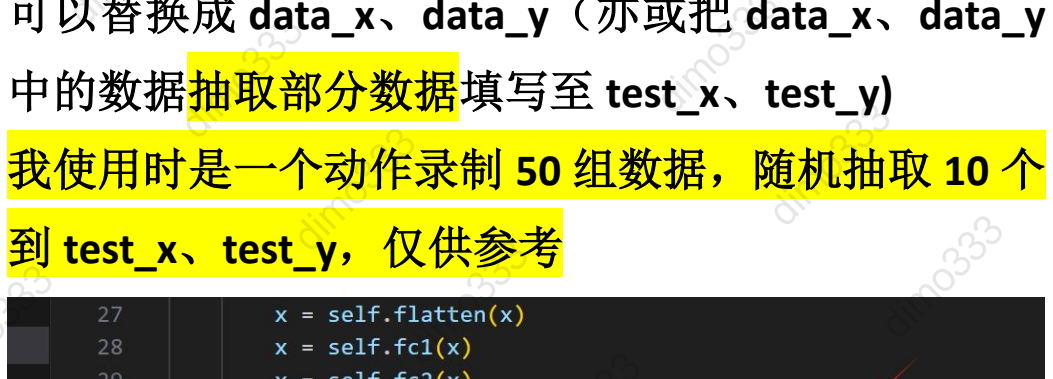
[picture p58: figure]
中的数据抽取部分数据填写至 test_x、test_y); 我使用时是一个动作录制 50 组数据，随机抽取 10 个 到 test_x、test_y，仅供参考; dimo333
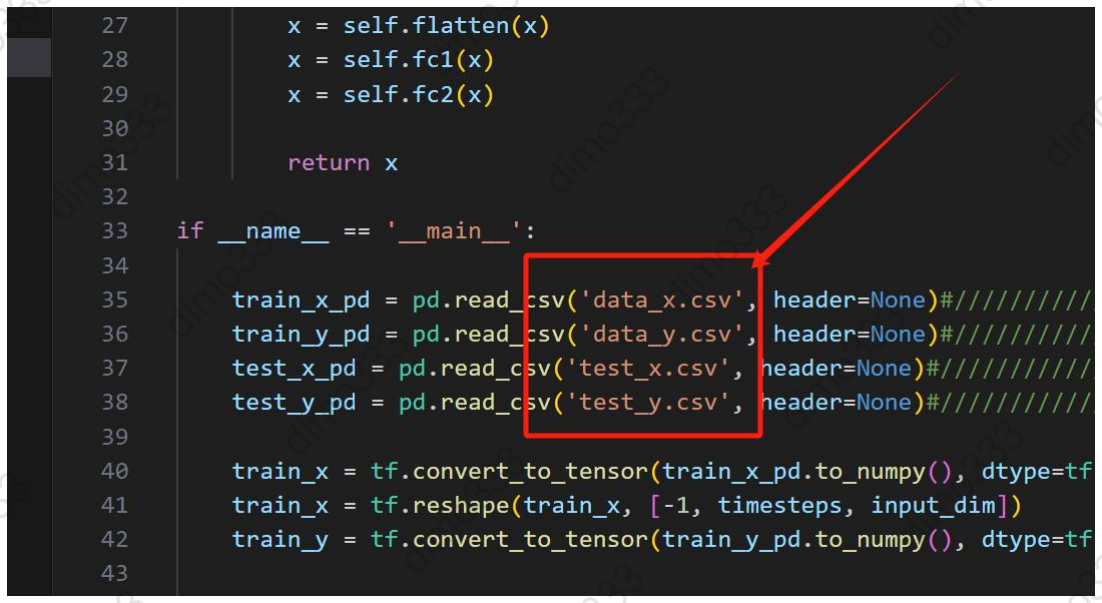
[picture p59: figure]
dimo333

25、一切准备就绪后右键点击 运行 python->在终端

## 中运行 python 文件

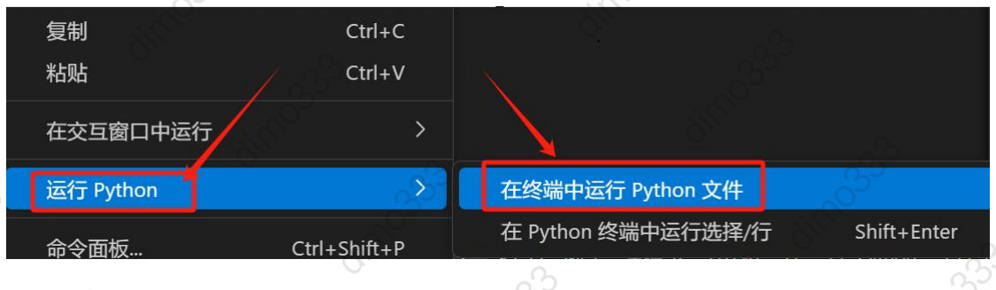
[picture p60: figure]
dimo333

dimo333

dimo333

dimo333

dimo333

dimo333

dimo333

dimo333

dimo333

dimo333

dimo333

dimo333

dimo333

dimo333

dimo333

dimo333

dimo333

dimo333

dimo333

dimo333

dimo333

dimo333

dimo333

dimo333

dimo333

dimo333

dimo333

dimo333

dimo333

dimo333

dimo333

dimo333

dimo333

dimo333

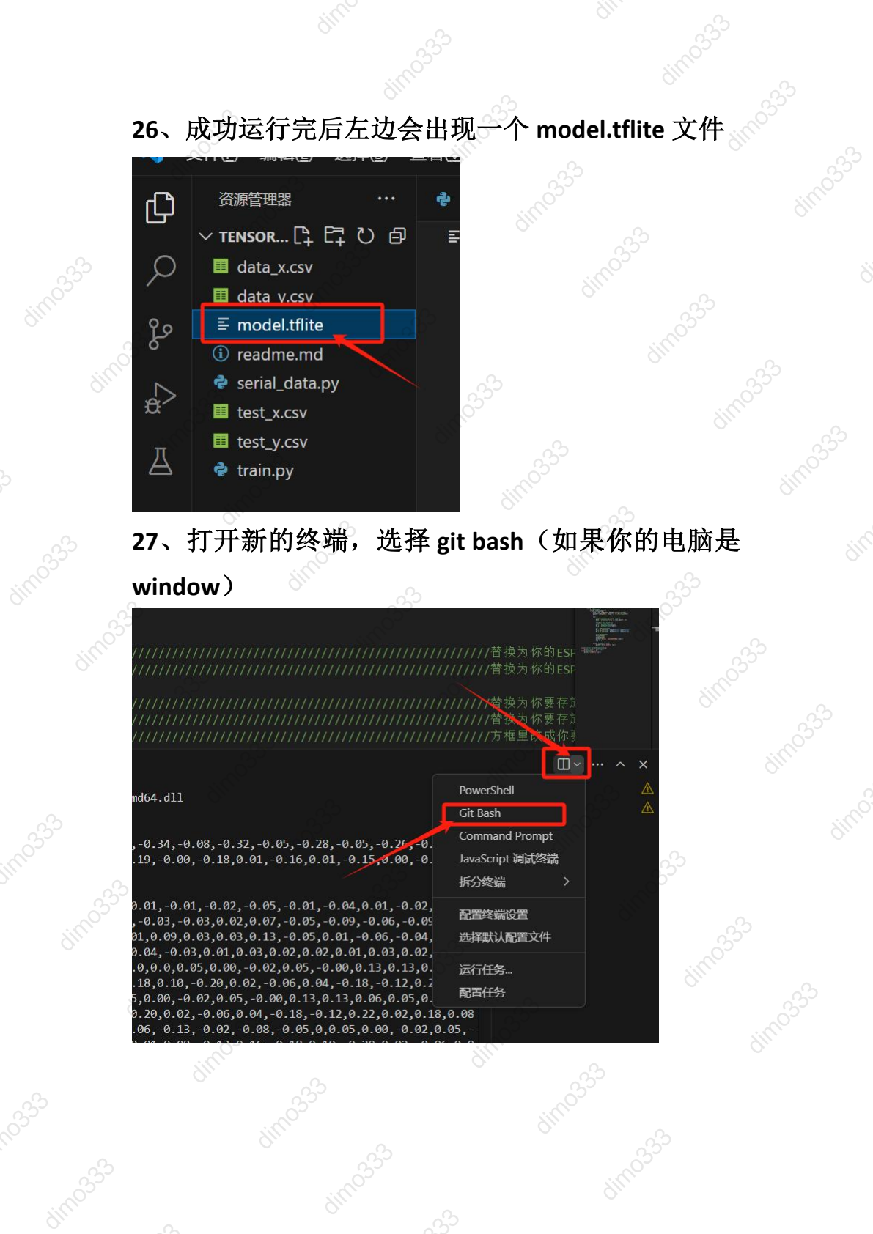
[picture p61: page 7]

26、成功运行完后左边会出现一个 model.tflite 文件

27、打开新的终端，选择 git bash（如果你的电脑是

## window）

dimo333

dimo333

dimo333

dimo333

dimo333

dimo333

dimo333

dimo333

dimo333

dimo333

dimo333

dimo333

dimo333

dimo333

dimo333

dimo333

dimo333

dimo333

dimo333

dimo333

dimo333

dimo333

dimo333

dimo333

dimo333

dimo333

dimo333

dimo333

dimo333

dimo333

dimo333

dimo333

dimo333

dimo333

dimo333

dimo333

dimo333

dimo333

dimo333

dimo333

dimo333

dimo333

dimo333

dimo333

dimo333

dimo333

dimo333

dimo333

dimo333

dimo333

28、在新的 gitbash 终端中输入指令并回车：

## ```xxd -i model.tflite > model.h```

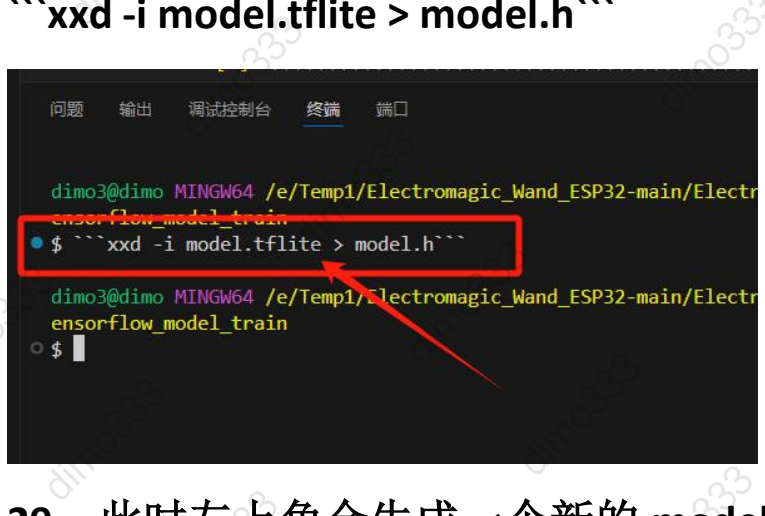
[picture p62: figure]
dimo333

29、此时左上角会生成一个新的 model.h 文件

dimo333

dimo333

dimo333

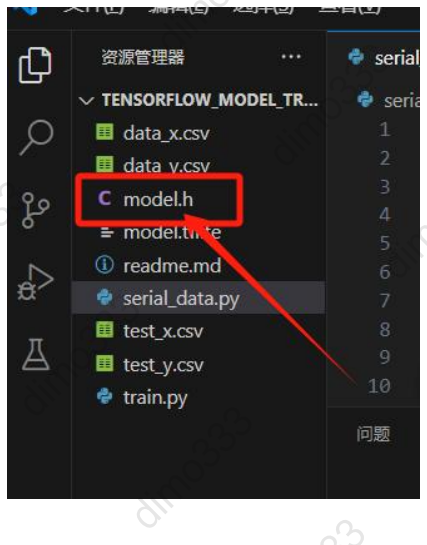
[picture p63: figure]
dimo333

dimo333

dimo333

dimo333

dimo333

dimo333

dimo333

dimo333

dimo333

dimo333

dimo333

dimo333

dimo333

dimo333

dimo333

dimo333

dimo333

dimo333

dimo333

dimo333

dimo333

dimo333

dimo333

dimo333

dimo333

dimo333

dimo333

dimo333

dimo333

dimo333

dimo333

dimo333

dimo333

dimo333

dimo333

dimo333

dimo333

dimo333

dimo333

dimo333

30、把这个文件复制，然后打开 wand 文件夹，与 wand 文件同级存放，以下以 wand_example 为例

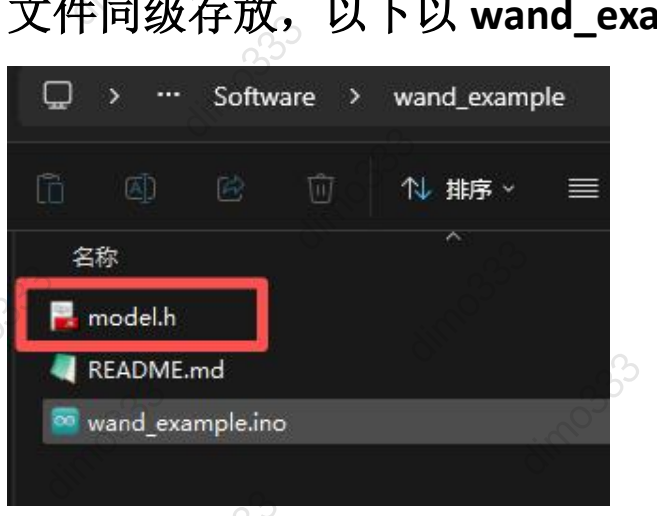
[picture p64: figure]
dimo333

31、替换掉原有的.h 模型文件

dimo333

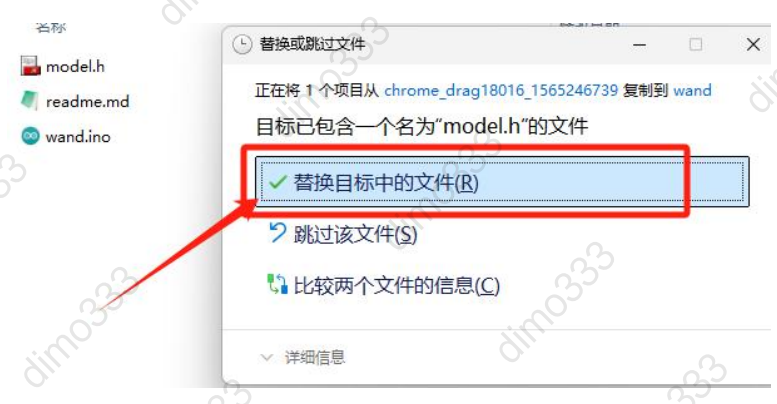
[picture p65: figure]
dimo333

dimo333

dimo333

dimo333

dimo333

dimo333

dimo333

dimo333

dimo333

dimo333

dimo333

dimo333

dimo333

dimo333

dimo333

dimo333

dimo333

dimo333

dimo333

dimo333

dimo333

dimo333

dimo333

dimo333

dimo333

dimo333

dimo333

dimo333

dimo333

dimo333

dimo333

dimo333

dimo333

dimo333

dimo333

dimo333

dimo333

dimo333

dimo333

dimo333

dimo333

32、此时再打开 wand 文件，调整一下你的代码（按

dimo333

键、动作对应的控制等）

dimo333

33、左上角点击上传

34、此时，你的 魔杖 就注魔完成了。

你可以开始使用你的魔杖了：点击按键->松开按键->
在两秒内做动作->魔杖识别并执行设置好的代码。

dimo333

dimo333

dimo333

dimo333

dimo333

dimo333

dimo333

dimo333

dimo333

dimo333

dimo333

dimo333

dimo333

dimo333

dimo333

dimo333

dimo333

dimo333

dimo333

dimo333

dimo333

dimo333

dimo333

dimo333

dimo333

dimo333

dimo333

dimo333

dimo333

dimo333

dimo333

dimo333

dimo333

dimo333

dimo333

dimo333

dimo333

dimo333

dimo333

dimo333

dimo333

dimo333

dimo333

dimo333

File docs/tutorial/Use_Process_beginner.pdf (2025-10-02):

按以下步骤执行可以验证模块是否能正常
工作

## 5、使用 arduinoIDE 打开 Get_Mpu6050_Data

6、修改好你要使用的按键引脚

dimo333

7、左上角选择 工具->开发板->选择你使用的 esp 开

发板的型号

dimo333

8、编译上传至开发板

dimo333

dimo333

dimo333

dimo333

dimo333

dimo333

dimo333

dimo333

dimo333

dimo333

dimo333

dimo333

dimo333

dimo333

dimo333

dimo333

dimo333

dimo333

dimo333

dimo333

dimo333

dimo333

dimo333

dimo333

dimo333

dimo333

dimo333

dimo333

dimo333

dimo333

dimo333

dimo333

dimo333

dimo333

dimo333

dimo333

dimo333

dimo333

dimo333

dimo333

dimo333

dimo333

dimo333

dimo333


简单的验证方法：
打开串口监视器：

此时按下按键后出现以下界面就代表能正常使用：

dimo333

dimo333

dimo333

dimo333

dimo333

dimo333

dimo333

dimo333

dimo333

dimo333

dimo333

dimo333

dimo333

dimo333

dimo333

dimo333

dimo333

dimo333

dimo333

dimo333

dimo333

dimo333

dimo333

dimo333

dimo333

dimo333

dimo333

dimo333

dimo333

dimo333

dimo333

dimo333

dimo333

dimo333

dimo333

dimo333

dimo333

dimo333

dimo333

dimo333

dimo333

dimo333

dimo333

dimo333

dimo333

dimo333

dimo333

dimo333

dimo333

dimo333

dimo333

dimo333

dimo333

dimo333

dimo333

dimo333

dimo333

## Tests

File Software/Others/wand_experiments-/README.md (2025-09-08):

ESP_BLE_KeyBoard
===
简述：这是一个模拟键盘信号的示例程序，我在代码里填写了一个简单的快捷输入helloworld，你可以根据自己的需要来更改。 <br>
来源：esp32_mouse_keyboard<br>
参考：https://github.com/asterics/esp32_mouse_keyboard<br>
注意事项：代码基于esp32_mouse_keyboard修改而来，部分参数可能并非最新最优，请自行修改；<br>
请把这个功能的zip文件添加到arduino库文件中；<br>
库文件可以在lib/中找到 具体流程：项目-->加载库-->添加.zip库-->找到并选择zip文件<br>

---

ESP_BLE_Mouse
===
简述：有三个不同的鼠标控制，对应的是esp32-wroom（x、z）；esp32c3（x、z);esp32（y、z); <br>
来源：esp32_mouse_keyboard<br>
参考：https://github.com/asterics/esp32_mouse_keyboard<br>
注意事项：代码基于esp32_mouse_keyboard修改而来，部分参数可能并非最新最优，请自行修改<br>
请把这个功能的zip文件添加到arduino库文件中<br>
库文件可以在lib/中找到 具体流程：项目-->加载库-->添加.zip库-->找到并选择zip文件<br>

---

IRremote
===
简述：在这个文件里，可以实现对红外信号的接收、存储及再发送。 代码只实现了基础的功能，后续还会优化（可能吧）<br>
来源：dimo333<br>
注意事项：代码版本较旧，部分参数可能并非最新最优，请自行修改<br>

---

light_band_1
===
简述：按一下发射一下<br>
来源：dimo333<br>
注意事项：代码版本较旧，部分参数可能并非最新最优，请自行修改<br>

---

light_band_2
===
简述：按一下从底下向上发射，再按一下从顶上向下发射<br>
来源：dimo333<br>
注意事项：代码版本较旧，部分参数可能并非最新最优，请自行修改<br>

---

（如果你都研究到这一份代码了，想必对你来说应该是小菜一碟）

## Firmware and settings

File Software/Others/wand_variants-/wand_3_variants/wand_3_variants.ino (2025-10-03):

#include <TensorFlowLite_ESP32.h>
#include "model.h"
#include "tensorflow/lite/micro/kernels/micro_ops.h"
#include "tensorflow/lite/micro/micro_error_reporter.h"
#include "tensorflow/lite/micro/micro_interpreter.h"
#include "tensorflow/lite/micro/all_ops_resolver.h"
#include "tensorflow/lite/schema/schema_generated.h"

#include <Wire.h>
#include <MPU6050.h>

//v5.0新增灯效库
#include <Adafruit_NeoPixel.h>

namespace {
tflite::ErrorReporter* error_reporter = nullptr;
const tflite::Model* model = nullptr;
tflite::MicroInterpreter* interpreter = nullptr;
TfLiteTensor* model_input = nullptr;


// ////////////////////////////////////////////////////////////////////////////////////////
const int num_classes = 6;  //动作（手势）的数量
const int input_dim = 2;    //传感器收集数据的维度
// ////////////////////////////////////////////////////////////////////////////////////////


constexpr int kTensorArenaSize = 50 * 1024;
uint8_t tensor_arena[kTensorArenaSize];
}

MPU6050 mpu;

// 定义每秒采样次数
const int freq = 100;
const int second = 2;
// const int freq = 64;
// const int second = 2;

// 重力分量
float gravity_x;
float gravity_y;
float gravity_z;

// 换算到x,y轴上的角速度
float roll_v, pitch_v;

// 上次更新时间
unsigned long prevTime;

// 三个状态，先验状态，观测状态，最优估计状态
float gyro_roll, gyro_pitch;        //陀螺仪积分计算出的角度，先验状态
float acc_roll, acc_pitch;          //加速度计观测出的角度，观测状态
float k_roll, k_pitch;              //卡尔曼滤波后估计出最优角度，最优估计状态

// 误差协方差矩阵P
float e_P[2][2];         //误差协方差矩阵，这里的e_P既是先验估计的P，也是最后更新的P

// 卡尔曼增益K
float k_k[2][2];         //这里的卡尔曼增益矩阵K是一个2X2的方阵


// ////////////////////////////////////////////////////////////////////////////////////////
const int buttonPin = 7; //定义按钮的引脚
const int Led_PIN0 = 0;   //led
const int IO_PIN2 = 2;  
const int IO_PIN4 = 4;
const int IO_PIN5 = 5;
const int IO_PIN6 = 6;  
const int Motor_PIN10 = 10;  //motor
// ////////////////////////////////////////////////////////////////////////////////////////





int buttonState = HIGH;      // 当前按钮状态，初始化为 HIGH
int lastButtonState = HIGH;  // 上一次按钮状态

unsigned long lastDebounceTime = 0; // 上一次去抖动时间
unsigned long debounceDelay = 10;   // 去抖动延时


// 全局变量-阈值-置信度（识别率）
float CONFIDENCE_THRESHOLD = 0.75;

// 全局变量-灯珠开关切换状态
bool switchState = false;  // false=关, true=开

// 全局变量-灯带灯效参数
#define NUM_LEDS 40///////////////////////////////////////////////////这里填写你想要控制灯的数量
#define DATA_PIN 1///////////////////////////////////////////////////这里填写你想要控制灯的引脚

Adafruit_NeoPixel strip = Adafruit_NeoPixel(NUM_LEDS, DATA_PIN, NEO_GRB + NEO_KHZ800);









void setup() {
  
  Serial.begin(115200);

  //灯带效果初始化
  strip.begin();
  strip.show();



  static tflite::MicroErrorReporter micro_error_reporter;  // NOLINT
  error_reporter = &micro_error_reporter;

  model = tflite::GetModel(model_tflite);
  if (model->version() != TFLITE_SCHEMA_VERSION) {
    error_reporter->Report(
      "Model provided is schema version %d not equal "
      "to supported version %d.",
      model->version(), TFLITE_SCHEMA_VERSION);
    return;
  }

  static tflite::AllOpsResolver resolver;
  resolver.AddConv2D();
  resolver.AddRelu();
  resolver.AddFullyConnected();
  resolver.AddSoftmax();
  resolver.AddReshape();
  resolver.AddTranspose();
  resolver.AddExpandDims();

  static tflite::MicroInterpreter static_interpreter(
    model, resolver, tensor_arena, kTensorArenaSize,
    error_reporter);
  interpreter = &static_interpreter;

  interpreter->AllocateTensors();
  model_input = interpreter->input(0);

  Wire.begin();
  mpu.initialize();

  if (!mpu.testConnection()) {
//    Serial.println("MPU6050连接失败");
    while (1);
  }

// ////////////////////////////////////////////////////////////////////////////////////////

  pinMode(buttonPin, INPUT_PULLUP); // 将按钮引脚设置为输入模式，并启用内部上拉电阻

  pinMode(Led_PIN0, OUTPUT);         //led
  digitalWrite(Led_PIN0, LOW);

  pinMode(IO_PIN2, OUTPUT);
  digitalWrite(IO_PIN2, LOW);

  pinMode(IO_PIN4, OUTPUT);
  digitalWrite(IO_PIN4, LOW);

  pinMode(IO_PIN5, OUTPUT);
  digitalWrite(IO_PIN5, LOW);

  pinMode(IO_PIN6, OUTPUT);
  digitalWrite(IO_PIN6, LOW);

  pinMode(Motor_PIN10, OUTPUT);     //motor
  digitalWrite(Motor_PIN10, LOW);

// ////////////////////////////////////////////////////////////////////////////////////////
  resetState();

  // 打印模型信息
//  Serial.print("模型地址: ");
//  Serial.println((uintptr_t)model_tflite, HEX);
//  Serial.print("模型长度: ");
//  Serial.println(model_tflite_len);

}









void loop() {
  int reading = digitalRead(buttonPin); // 读取按钮引脚的电平状态

  // 检查是否有按钮状态变化
  if (reading != lastButtonState) {
    lastDebounceTime = millis(); // 记录状态变化的时间
  }

  // 如果状态变化超过去抖动延时，认为是有效变化
  if ((millis() - lastDebounceTime) > debounceDelay) {
    // 如果按钮状态确实变化了
    if (reading != buttonState) {
      buttonState = reading;

      // 只有在按钮从按下变为释放时，才开始主流程
      if (buttonState == HIGH) {

        //震动马达震动
        digitalWrite(Motor_PIN10, HIGH);
        delay(200);
        digitalWrite(Motor_PIN10, LOW);
        
//        delay(200);
//        digitalWrite(IO_PIN5, HIGH);
//        delay(600);
//        digitalWrite(IO_PIN5, LOW);

        resetState();

        for (int i = 0; i < freq * second; i++) {
          get_kalman_mpu_data(i, model_input->data.f);
        }

        TfLiteStatus invoke_status = interpreter->Invoke();
        if (invoke_status != kTfLiteOk) {
          error_reporter->Report("Invoke failed");
          return;
        }

        // ====== 新增部分：带置信度判断 ======
        float* output = interpreter->output(0)->data.f;
        float confidence;
        int gesture = processGesture(output, &confidence);

        if (confidence >= CONFIDENCE_THRESHOLD) {
//          Serial.print("识别成功: 手势 = ");
//          Serial.print(gesture);
//          Serial.print("，置信度 = ");
//          Serial.println(confidence, 2);

          //震动马达震动0.2s----识别成功震动
          digitalWrite(Motor_PIN10, HIGH);
          delay(10);
          
          energyGatherAndBurst(30, 10); //灯带效果-调整这些值来控制效果速度-耗时2.1s

          digitalWrite(Motor_PIN10, LOW);
          delay(10);


          executeGesture(gesture);  // 执行动作

        } else {
//          Serial.print("识别失败，置信度 = ");
//          Serial.println(confidence, 2);

          //震动马达震动0.2s*2=0.5s----识别失败震动
          digitalWrite(Motor_PIN10, HIGH);
          delay(200);
          digitalWrite(Motor_PIN10, LOW);
          delay(100);
          digitalWrite(Motor_PIN10, HIGH);
          delay(200);
          digitalWrite(Motor_PIN10, LOW);
          delay(10);


        }
        // ====== 到这里结束 ======
      }
    }
  }

  // 记录上一次按钮状态
  lastButtonState = reading;
}


//  灯带效果函数
void energyGatherAndBurst(uint8_t gatherDelay, uint8_t burstDelay) {
  int baseLeds = 10;  // 前10个灯

  // 聚集效果 - 前10个LED依次点亮
  for (int i = 0; i < baseLeds; i++) {
    for (int brightness = 0; brightness <= 255; brightness += 50) {
      strip.setPixelColor(i, strip.Color(100, 100, brightness));  //这三个值就是蓄力的参数-目前蓝
      strip.show();
      delay(gatherDelay);
    }
  }

  // 爆发效果 - LED从底部快速移动到顶部
  strip.clear();
  for (int i = 0; i < baseLeds; i++) {
    strip.setPixelColor(i, strip.Color(100, 100, 255));
  }
  strip.show();
  delay(burstDelay);

  for (int i = 1; i <= strip.numPixels() - baseLeds; i++) {
    strip.clear();
    for (int j = 0; j < baseLeds; j++) {
      strip.setPixelColor(i + j, strip.Color(100, 100, 255));
    }
    strip.show();
    delay(burstDelay);
  }

  strip.clear();
  strip.show();
  delay(10);
}







//初始化陀螺仪、加速度计状态和协方差矩阵、为后续卡尔曼滤波做准备
void resetState() {
  // 读取加速度计数据
  int16_t ax, ay, az;
  mpu.getAcceleration(&ax, &ay, &az);

  // 转换加速度计数据为g值
  float Ax = ax / 16384.0;
  float Ay = ay / 16384.0;
  float Az = az / 16384.0;

  // 计算Pitch和Roll
  k_pitch = -atan2(Ax, sqrt(Ay * Ay + Az * Az));
  k_roll = atan2(Ay, Az);

  // 误差协方差矩阵P
  e_P[0][0] = 1;
  e_P[0][1] = 0;
  e_P[1][0] = 0;
  e_P[1][1] = 1;

  // 卡尔曼增益K
  k_k[0][0] = 0;
  k_k[0][0] = 0;
  k_k[0][0] = 0;
  k_k[0][0] = 0;

  prevTime = millis();
}

//采集一帧 MPU6050 数据、并进行卡尔曼滤波、提取干净的动作特征
void get_kalman_mpu_data(int i, float* input) {
  // 计算微分时间
  unsigned long currentTime = millis();
  float dt = (currentTime - prevTime) / 1000.0; // 时间间隔（秒）
  prevTime = currentTime;

  // 获取角速度和加速度
  int16_t ax, ay, az, gx, gy, gz;
  mpu.getMotion6(&ax, &ay, &az, &gx, &gy, &gz);

  // 转换加速度计数据为g值
  float Ax = ax / 16384.0;
  float Ay = ay / 16384.0;
  float Az = az / 16384.0;
  float Ox, Oy, Oz;

  // 转换陀螺仪数据为弧度/秒
  float Gx = gx / 131.0 / 180 * PI;
  float Gy = gy / 131.0 / 180 * PI;
  float Gz = gz / 131.0 / 180 * PI;

  // step1:计算先验状态
  // 计算roll, pitch, yaw轴上的角速度
  roll_v = Gx + ((sin(k_pitch) * sin(k_roll)) / cos(k_pitch)) * Gy + ((sin(k_pitch) * cos(k_roll)) / cos(k_pitch)) * Gz; //roll轴的角速度
  pitch_v = cos(k_roll) * Gy - sin(k_roll) * Gz; //pitch轴的角速度
  gyro_roll = k_roll + dt * roll_v; //先验roll角度
  gyro_pitch = k_pitch + dt * pitch_v; //先验pitch角度

  // step2:计算先验误差协方差矩阵
  e_P[0][0] = e_P[0][0] + 0.0025;//这里的Q矩阵是一个对角阵且对角元均为0.0025
  e_P[0][1] = e_P[0][1] + 0;
  e_P[1][0] = e_P[1][0] + 0;
  e_P[1][1] = e_P[1][1] + 0.0025;

  // step3:更新卡尔曼增益
  k_k[0][0] = e_P[0][0] / (e_P[0][0] + 0.3);
  k_k[0][1] = 0;
  k_k[1][0] = 0;
  k_k[1][1] = e_P[1][1] / (e_P[1][1] + 0.3);

  // step4:计算最优估计状态
  // 观测状态
  // roll角度
  acc_roll = atan2(Ay, Az);
  //pitch角度
  acc_pitch = -atan2(Ax, sqrt(Ay * Ay + Az * Az));
  // 最优估计状态
  k_roll = gyro_roll + k_k[0][0] * (acc_roll - gyro_roll);
  k_pitch = gyro_pitch + k_k[1][1] * (acc_pitch - gyro_pitch);

  // step5:更新协方差矩阵
  e_P[0][0] = (1 - k_k[0][0]) * e_P[0][0];
  e_P[0][1] = 0;
  e_P[1][0] = 0;
  e_P[1][1] = (1 - k_k[1][1]) * e_P[1][1];

  // 计算重力加速度方向
  gravity_x = -sin(k_pitch);
  gravity_y = sin(k_roll) * cos(k_pitch);
  gravity_z = cos(k_roll) * cos(k_pitch);

  // 重力消除
  Ax = Ax - gravity_x;
  Ay = Ay - gravity_y;
  Az = Az - gravity_z;

  // 得到全局空间坐标系中的相对加速度
  Ox = cos(k_pitch) * Ax + sin(k_pitch) * sin(k_roll) * Ay + sin(k_pitch) * cos(k_roll) * Az;
  Oy = cos(k_roll) * Ay - sin(k_roll) * Az;
  Oz = -sin(k_pitch) * Ax + cos(k_pitch) * sin(k_roll) * Ay + cos(k_pitch) * cos(k_roll) * Az;

  input[i * input_dim] = Oy*9.8;
  input[i * input_dim + 1] = Oz*9.8;

  delay(1000 / freq); // 短暂延迟，避免过高的循环频率
}



//
int processGesture(float* output, float* confidence_out) {
//  Serial.println("模型输出:");
  int max_index = 0;
  float max_value = output[0];

  for (int i = 0; i < num_classes; i++) {
//    Serial.print("output[");
//    Serial.print(i);
//    Serial.print("] = ");
//    Serial.println(output[i]);
    if (output[i] >= max_value) {
      max_value = output[i];
      max_index = i;
    }
  }

//  Serial.print("最大置信度: ");
//  Serial.println(max_value);
//  Serial.println(max_index);
  *confidence_out = max_value; // 传出置信度

  return max_index; // 返回识别到的动作编号
}

void executeGesture(int index) {
  if (index == 0) {
//    Serial.println("执行 0Cricle 对应动作");

    //开关1闭合0.6s
    digitalWrite(IO_PIN2, HIGH);
    delay(400);
    digitalWrite(IO_PIN2, LOW);
    delay(10);

  } else if (index == 1) {
//    Serial.println("执行 1Horn 对应动作");

    //开关2闭合0.6s
    digitalWrite(IO_PIN4, HIGH);
    delay(400);
    digitalWrite(IO_PIN4, LOW);
    delay(10);


  }else if (index == 2) {
//    Serial.println("执行 2 对应动作");

    //开关3闭合0.6s
    digitalWrite(IO_PIN5, HIGH);
    delay(400);
    digitalWrite(IO_PIN5, LOW);
    delay(10);


  }else if (index == 3) {
//    Serial.println("执行 3 对应动作");

    //开关4闭合0.6s
    digitalWrite(IO_PIN6, HIGH);
    delay(400);
    digitalWrite(IO_PIN6, LOW);
    delay(10);


  }else if (index == 4) {
//    Serial.println("执行 4 对应动作");

//    switchState = !switchState;  // 每次取反，切换状态

//    if (switchState) {
//        digitalWrite(Led_PIN0, HIGH);// 开
//    } else {
//        digitalWrite(Led_PIN0, LOW);// 关
//    }

     //常亮大延迟后关闭
     digitalWrite(Led_PIN0, HIGH);// 开
     delay(10000);  //10s
     digitalWrite(Led_PIN0, LOW);// 关




  }else if (index == 5) {
//    Serial.println("执行 5 对应动作");

    


  }
}

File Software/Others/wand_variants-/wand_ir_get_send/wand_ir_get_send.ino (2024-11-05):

#include <TensorFlowLite_ESP32.h>
#include "model.h"
#include "tensorflow/lite/micro/kernels/micro_ops.h"
#include "tensorflow/lite/micro/micro_error_reporter.h"
#include "tensorflow/lite/micro/micro_interpreter.h"
#include "tensorflow/lite/micro/all_ops_resolver.h"
#include "tensorflow/lite/schema/schema_generated.h"

#include <Wire.h>
#include <MPU6050.h>

namespace {
  tflite::ErrorReporter* error_reporter = nullptr;
  const tflite::Model* model = nullptr;
  tflite::MicroInterpreter* interpreter = nullptr;
  TfLiteTensor* model_input = nullptr;

  const int num_classes = 5;
  const int input_dim = 2;

  constexpr int kTensorArenaSize = 50 * 1024;
  uint8_t tensor_arena[kTensorArenaSize];

  MPU6050 mpu;
  unsigned long prevTime;
  const int freq = 100;   // 每秒采样次数
  const int second = 2;   // 采样时长（秒）
  const int buttonPin = 7;
  const int ledPin = 1;
  const int irReceiverPin = 6;
  const int IREMITTERPIN = 4;
  const int ledChannel = 0;
  const int frequency = 38000;
  const int resolution = 8;

  bool IRNOW = false;
  bool IRGET = false;
  bool buttonPressed = false;
  int buttonState, lastButtonState = HIGH;
  unsigned long lastDebounceTime = 0;
  unsigned long debounceDelay = 10;
  volatile unsigned long lastChangeTime = 0;
  volatile unsigned long pulseWidth;
  volatile enum { EMPTY, RECORDING, READY } state = EMPTY;
  volatile unsigned long irBuffer[400];
  volatile int irIndex = 0;
}

float gravity_x, gravity_y, gravity_z;
float roll_v, pitch_v;
float gyro_roll, gyro_pitch;
float acc_roll, acc_pitch;
float k_roll, k_pitch;
float e_P[2][2];
float k_k[2][2];

void setup() {
  Serial.begin(115200);
  pinMode(irReceiverPin, INPUT_PULLUP);
  pinMode(buttonPin, INPUT_PULLUP);
  pinMode(IREMITTERPIN, OUTPUT);
  ledcSetup(ledChannel, frequency, resolution);
  ledcAttachPin(IREMITTERPIN, ledChannel);
  attachInterrupt(digitalPinToInterrupt(irReceiverPin), handleInterrupt, CHANGE);

  static tflite::MicroErrorReporter micro_error_reporter;
  error_reporter = &micro_error_reporter;

  model = tflite::GetModel(model_tflite);
  if (model->version() != TFLITE_SCHEMA_VERSION) {
    error_reporter->Report("Model version mismatch");
    return;
  }

  static tflite::AllOpsResolver resolver;
  resolver.AddConv2D();
  resolver.AddRelu();
  resolver.AddFullyConnected();
  resolver.AddSoftmax();
  resolver.AddReshape();
  resolver.AddTranspose();
  resolver.AddExpandDims();

  static tflite::MicroInterpreter static_interpreter(model, resolver, tensor_arena, kTensorArenaSize, error_reporter);
  interpreter = &static_interpreter;
  interpreter->AllocateTensors();
  model_input = interpreter->input(0);

  Wire.begin();
  mpu.initialize();
  if (!mpu.testConnection()) {
    Serial.println("MPU6050 connection failed");
    while (1);
  }

  pinMode(ledPin, OUTPUT);
  digitalWrite(ledPin, LOW);
  resetState();
}

void loop() {
  int reading = digitalRead(buttonPin);
  if (reading != lastButtonState) {
    lastDebounceTime = millis();
  }

  if ((millis() - lastDebounceTime) > debounceDelay) {
    if (reading != buttonState) {
      buttonState = reading;
      if (buttonState == HIGH) {
        Serial.println("Button pressed");
        resetState();

        for (int i = 0; i < freq * second; i++) {
          get_kalman_mpu_data(i, model_input->data.f);
        }

        if (interpreter->Invoke() != kTfLiteOk) {
          error_reporter->Report("Invoke failed");
          return;
        }

        processGesture(interpreter->output(0)->data.f);
      }
    }
  }

  lastButtonState = reading;
}

void resetState() {
  int16_t ax, ay, az;
  mpu.getAcceleration(&ax, &ay, &az);

  float Ax = ax / 16384.0;
  float Ay = ay / 16384.0;
  float Az = az / 16384.0;

  k_pitch = -atan2(Ax, sqrt(Ay * Ay + Az * Az));
  k_roll = atan2(Ay, Az);

  e_P[0][0] = e_P[1][1] = 1;
  e_P[0][1] = e_P[1][0] = 0;

  k_k[0][0] = k_k[1][1] = 0;
  prevTime = millis();
}

void get_kalman_mpu_data(int i, float* input) {
  unsigned long currentTime = millis();
  float dt = (currentTime - prevTime) / 1000.0;
  prevTime = currentTime;

  int16_t ax, ay, az, gx, gy, gz;
  mpu.getMotion6(&ax, &ay, &az, &gx, &gy, &gz);

  float Ax = ax / 16384.0;
  float Ay = ay / 16384.0;
  float Az = az / 16384.0;
  float Gx = gx / 131.0 / 180 * PI;
  float Gy = gy / 131.0 / 180 * PI;
  float Gz = gz / 131.0 / 180 * PI;

  roll_v = Gx + ((sin(k_pitch) * sin(k_roll)) / cos(k_pitch)) * Gy + ((sin(k_pitch) * cos(k_roll)) / cos(k_pitch)) * Gz;
  pitch_v = cos(k_roll) * Gy - sin(k_roll) * Gz;
  gyro_roll = k_roll + dt * roll_v;
  gyro_pitch = k_pitch + dt * pitch_v;

  e_P[0][0] += 0.0025;
  e_P[1][1] += 0.0025;

  k_k[0][0] = e_P[0][0] / (e_P[0][0] + 0.3);
  k_k[1][1] = e_P[1][1] / (e_P[1][1] + 0.3);

  acc_roll = atan2(Ay, Az);
  acc_pitch = -atan2(Ax, sqrt(Ay * Ay + Az * Az));

  k_roll = gyro_roll + k_k[0][0] * (acc_roll - gyro_roll);
  k_pitch = gyro_pitch + k_k[1][1] * (acc_pitch - gyro_pitch);

  e_P[0][0] *= (1 - k_k[0][0]);
  e_P[1][1] *= (1 - k_k[1][1]);

  gravity_x = -sin(k_pitch);
  gravity_y = sin(k_roll) * cos(k_pitch);
  gravity_z = cos(k_roll) * cos(k_pitch);

  Ax -= gravity_x;
  Ay -= gravity_y;
  Az -= gravity_z;

  float Ox = cos(k_pitch) * Ax + sin(k_pitch) * sin(k_roll) * Ay + sin(k_pitch) * cos(k_roll) * Az;
  float Oz = -sin(k_pitch) * Ax + cos(k_pitch) * sin(k_roll) * Ay + cos(k_pitch) * cos(k_roll) * Az;

  input[i * input_dim] = Ox;
  input[i * input_dim + 1] = Oz;

  delay(1000 / freq);
}

void processGesture(float* output) {
  int max_index = 0;
  float max_value = output[0];

  for (int i = 1; i < num_classes; i++) {
    if (output[i] > max_value) {
      max_value = output[i];
      max_index = i;
    }
  }

  if (max_index == 0) {
    Serial.println("_UpAndDown_");
   
      irsend(); // 发送红外信号
    
  } else if (max_index == 1) {
    Serial.println("_RightAngle_");
  } else if (max_index == 2) {
    Serial.println("_Letter_W_");
  } else if (max_index == 3) {
    Serial.println("_SharpAngle_");
  } else if (max_index == 4) {
    Serial.println("_Horn_");
     if(IRNOW == false){
      IRGET = true; // 设置接收模式
      IRNOW = true; // 标记正在接收
    }
  }
}

void irsend() {
  detachInterrupt(digitalPinToInterrupt(irReceiverPin));

  Serial.println("Sending IR signal");

  for (int i = 0; i < irIndex; i++) {
    ledcWrite(ledChannel, (i % 2 == 0) ? 128 : 0);
    delayMicroseconds(irBuffer[i]);
  }

  ledcWrite(ledChannel, 0);
  // 打印接收到的数据
  for (int i = 0; i < irIndex; i++) {
    Serial.print(i);
    Serial.print("-");
    Serial.print(irBuffer[i]);
    Serial.println(); 
  }
  attachInterrupt(digitalPinToInterrupt(irReceiverPin), handleInterrupt, CHANGE);
}
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

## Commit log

2024-10-20 README.md
    项目说明
2024-10-21 Create IRremote
    红外信号的接收、存储和发送
2024-10-22 Create 引脚图
2025-09-21 Add files via upload
    上传新的可视化工具
2025-10-02 Add files via upload
    上传新的教程，更详细，更完善
